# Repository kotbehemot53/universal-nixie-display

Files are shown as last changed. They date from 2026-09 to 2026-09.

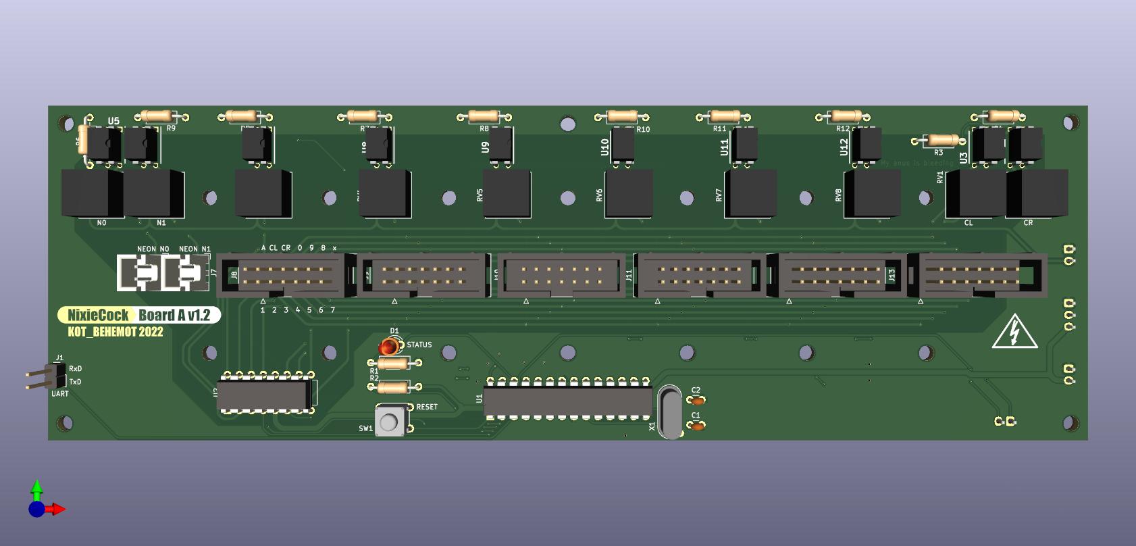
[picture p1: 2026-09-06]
hardware/nixie-board/images/nixie-board-3d-front.jpg

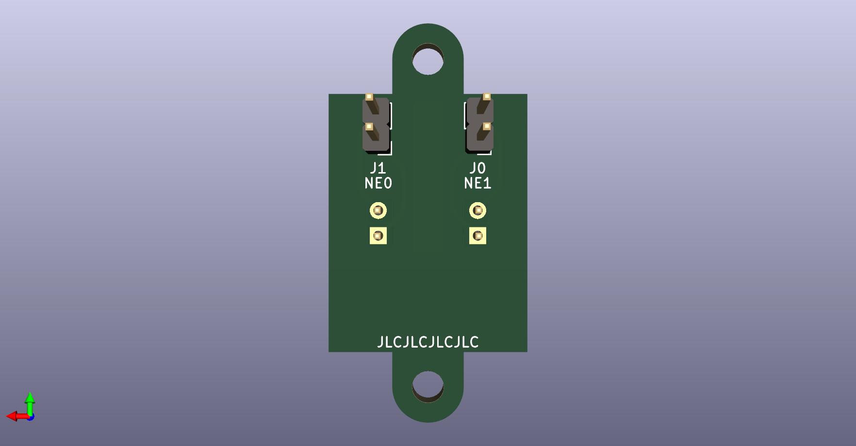
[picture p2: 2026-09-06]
hardware/sockets/neon/images/neonBoard-3d-back.jpg

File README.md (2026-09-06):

Universal Nixie Display
=======================

This is the central project for the open source software and hardware for the Universal Nixie Display.
The display is something more than a desktop nixie clock - it can be whatever you want it to be by
displaying not only time but also weather data or any data you want it to display.

**At the moment it is a work in progress.**

Physical Components
-------------------

The display is modular. Each board works on its own (or with a different master), the default
configuration is:

- **Nixie board** (top): up to 6 nixie tubes (attached via pluggable socket boards with current-limiting
  trimmers, so various nixie models can be used) + up to 2 neon lamps. Driven by an ATmega328P that
  receives commands over I²C (address `0x4`).
- **VFD board** (bottom): one IV-18 8-digit 7-segment VFD tube. Driven by an ATmega328P that receives
  commands over I²C (address `0x5`).
- **Pi hat**: sits on a Raspberry Pi, sends commands to the boards above, takes power from an external
  supply and distributes it, and exposes connectors for control buttons / knobs and the power button.
- **Socket boards**: small per-tube-model boards (IN-14, Z573M) and a neon lamp board that plug into
  the nixie board.

Operating principles
--------------------

The microcontrollers provide low-level control over the displays - multiplexing, dimming, displaying
letters or digits, simple animations. The Raspberry communicates with them using I²C and sends simple
commands (what characters to display, at what brightness etc.). There are python scripts on the
Raspberry that can obtain various data (e.g. weather data from Ruuvi sensors, time from an RTC,
whatever else the user wants) and pass it to be displayed on the nixies and VFD using provided python
libraries that wrap the microcontroller commands in an easy-to-use API.

By default the nixies are meant to be used as the "main" display, whereas the VFD is a "secondary"
display, used to show currently chosen options etc. But it's up to the user to decide how they want to
use them.

Repository layout
-----------------

```
firmware/
  nixie-controller/   PlatformIO project, ATmega328P firmware for the nixie board
  vfd-controller/     PlatformIO project, ATmega328P firmware for the VFD board
software/
  raspberry/          Python scripts + systemd units for the Raspberry Pi master
hardware/
  nixie-board/        KiCad project of the nixie board
  vfd-board/          KiCad project of the VFD board
  pi-hat/             KiCad project of the Raspberry Pi hat
  sockets/            KiCad projects of the tube socket boards (in14, z573m, neon)
  lib/                Shared KiCad symbol / footprint / 3D libraries used by the boards above
scratch/
  kicad-experiments/  Throwaway KiCad experiments, not part of the product
```

See `hardware/README.md` for the board naming history, PCB variants and fabrication files.

Each firmware directory is a self-contained PlatformIO project - open it directly in PlatformIO / your
IDE. Everything in this repository is licensed under the GPLv3 (see `LICENSE`).

History
-------

This repository was assembled from several previous ones (the firmware and Raspberry code used to live
in separate repos pulled in as git submodules, the hardware lived in an older private repo). Their git
histories were rewritten into subdirectories and merged here, so `git log --follow` works on the
imported files. Old feature branches were kept under the `nixie-controller/`, `vfd-controller/` and
`raspberry/` branch prefixes, VFD firmware releases are tagged `vfd-controller/<version>`.

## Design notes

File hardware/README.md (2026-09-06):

Hardware
========

KiCad projects for all boards of the Universal Nixie Display. Files are KiCad 6/7 format
(`kicad_sch` version 20211123 / 20230121, `kicad_pcb` version 20211014 / 20221018), open them with
KiCad 7 or newer and let it upgrade the format when you first save.

```
nixie-board/    top board: up to 6 nixies + 2 neons, ATmega328P, I2C slave 0x4
vfd-board/      bottom board: IV-18 VFD, ATmega328P, I2C slave 0x5
pi-hat/         Raspberry Pi hat: power in, I2C master, buttons / knobs, power button
sockets/
  in14/         IN-14 nixie socket board (plugs into nixie-board)
  z573m/        Z573M nixie socket board (plugs into nixie-board)
  neon/         neon lamp board (plugs into nixie-board)
lib/            shared symbol / footprint / 3D model libraries (see lib/README.md)
```

Every board directory has the same shape:

- `<board>.kicad_pro / .kicad_sch / .kicad_pcb` - the current design,
- `<board>-bom.csv` - BOM exported from the schematic (where one existed),
- `sym-lib-table` / `fp-lib-table` - project library tables, all pointing into `../lib` (or `../../lib`
  for the socket boards) via `${KIPRJMOD}`,
- `fab/` - gerber zips that were actually sent to a fab house, kept as-is for reference,
- `variants/` - alternative PCB layouts of the same schematic (autorouter pre-fills, different track
  styles, earlier revisions). They are standalone `.kicad_pro` + `.kicad_pcb` pairs, open them directly.
  They are kept for reference only, the file next to the `.kicad_sch` is the current one,
- `images/` - schematic exports and 3D renders.

Symbols and footprints are embedded in the schematic / PCB files, so the boards open and render even if
a library entry is missing. The library tables only matter when you want to update a part from its
library.

Checking library resolution
---------------------------

Library links were verified headless with KiCad 10.0.1 (`kicad-cli pcb drc` / `sch erc` with
`--severity-all`, then filter for `lib_footprint_issues` / `lib_symbol_issues`). All project libraries
resolve. The remaining "not found in library" reports come from parts that the *official* KiCad
libraries renamed or removed since the boards were drawn, not from this repository:

| Reference in the design | Boards | Status in KiCad 10 official libs |
|---|---|---|
| `Button_Switch_THT:SW_TH_Tactile_Omron_B3F-10xx` | nixie-board, vfd-board | split into `SW_TH_Tactile_Omron_B3F-100x` / `-102x` / ... |
| `Symbol:Symbol_HighVoltage_Type2_CopperTop_VerySmall`| nixie-board, vfd-board | removed, only `Symbol_HighVoltage_Triangle_*` remain |
| `Connector:Conn_01x02_Male` / `_Female` / `Conn_01x03_Male` / `Conn_01x07_Female` | nixie-board, vfd-board, sockets | moved to `Connector_Generic` |
| `Device:Q_NMOS_SGD`, `Device:Q_NPN_CBE` | pi-hat-tht variant | replaced by `Q_NMOS_GSD` / `Q_NPN_BCE` pin-order variants |

The `variants/` directories carry their own `fp-lib-table` / `sym-lib-table` (same entries, one `../`
deeper), because KiCad treats whatever directory the `.kicad_pro` sits in as the project root.

The embedded copies still work, so nothing needs to change unless a part is re-placed from the library.
"Does not match its copy in the library" warnings are expected for the same reason (embedded 2022/2023
copies vs. current library versions). `kibuzzard-*` footprints are text labels generated by the
KiBuzzard plugin and never had a library.

3D models
---------

Standard-library 3D models are referenced as `${KICAD6_3DMODEL_DIR}/<lib>.3dshapes/<name>.step`. KiCad 7+
maps the old versioned variable to the current install automatically. The references were originally
`.wrl`; KiCad 9+ ships only `.step` files and does *not* fall back from `.wrl` to `.step`, so every
generic part rendered as missing until the extensions were rewritten. Five models were dropped or renamed
upstream and still show as missing in the 3D viewer, which is cosmetic:

| Model | Board |
|---|---|
| `Potentiometer_THT/Potentiometer_Bourns_3386F_Vertical` (9x) | nixie-board |
| `Button_Switch_THT/SW_TH_Tactile_Omron_B3F-10xx` | vfd-board |
| `Module/Raspberry_Pi_Zero_Socketed_THT_FaceDown_MountingHoles` | vfd-board, pi-hat |
| `Connector_USB/USB_Micro-B_Amphenol_10103594-0001LF_Horizontal` | pi-hat |
| `Connector_Wire/SolderWire-0.75sqmm_1x02_P4.8mm_D1.25mm_OD2.3mm`  | pi-hat |

Vendored SamacSys models live in `lib/SamacSys_Parts.3dshapes/` and are referenced via `${KIPRJMOD}`.

Naming history
--------------

The boards were renamed when the projects were moved into this repository. Old names still appear in
title blocks, net names and library nicknames (`Nixiecock1`, `nixieCockB`), which were intentionally
left alone so nothing inside the design files had to be touched apart from 3D model paths.

| Old project (piclock repo) | Here | Notes |
|---|---|---|
| `kicad/nixiecock1` | `nixie-board` | "Board A" |
| `kicad/nixiecockB` | `vfd-board` | "Board B" |
| `kicad/pihat/pihat` `pihat_smd.kicad_sch/.kicad_pro` | `pi-hat`  | SMD version, current schematic |
| `kicad/pihat/pihat` `pihat_smd-rounded-blah.kicad_pcb` | `pi-hat.kicad_pcb` | current layout (rounded tracks), the one that was fabbed |
| `kicad/pihat/pihat` `pihat_smd.kicad_pcb` | `pi-hat/variants/pi-hat_unrounded` | same layout before track rounding |
| `kicad/pihat/pihat` `pihat.*` | `pi-hat/variants/pi-hat-tht` | older THT version, has its own schematic |
| `kicad/IN-14Board` | `sockets/in14` | file names unchanged (`in14board.*`) |
| `kicad/z573mBoard` | `sockets/z573m` | file names unchanged (`z573mBoard.*`) |
| `kicad/neonBoard` | `sockets/neon` | file names unchanged (`neonBoard.*`) |
| `kicad/xprmnt` | `../scratch/kicad-experiments` | was gitignored before |

Fabrication files vs. layouts (from file timestamps, verify before reusing):

- `pi-hat/fab/gerber5.zip` matches `pi-hat.kicad_pcb` (the rounded-track layout).
- `nixie-board/fab/gerber_A2`, `gerber_A3` and `vfd-board/fab/gerber_B1..B3` predate the last PCB
  edits of those boards; treat the highest number as the last one ordered.
- `sockets/in14/fab/gerbers7.zip` and `sockets/z573m/fab/gerber3.zip` match the current PCBs.

What was dropped on import
--------------------------

Regenerable or per-user files were not carried over: `*-backups/`, `.history/`, `fp-info-cache`,
`*.kicad_prl`, `*.kicad_sch-bak`, `*.xml` netlists, lock files, unzipped gerber directories that also
existed as zips, and the vendor library zips (`KiCadLibs-master.zip`, SamacSys `LIB_*.zip`) whose
relevant content is now in `lib/`.

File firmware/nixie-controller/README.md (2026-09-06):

Universal Nixie Display
=======================

Nixie microcontroller
---------------------

Hardware: Atmega328p

*This is a work in progress*

Controls the Board A of the Universal Nixie Display (the Nixie module).
Receives commands via I²C.

The current device address is `0x4`.

Available commands
------------------

See the `CMD_` constants in `main.cpp` and their comments.

TODO
----

- refactor the code based on the current VFD Display Firmware architecture
  (`../vfd-controller`).

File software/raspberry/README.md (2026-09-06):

Universal Nixie Display
=======================

Raspberry master
----------------

Hardware: Raspberry Pi Zero W or any other with Wi-Fi support

*This is a work in progress*

Reads signals from an external control panel and runs appropriate features on the Universal Nixie Display boards A and B.

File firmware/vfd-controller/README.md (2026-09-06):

Universal Nixie Display
=======================

VFD microcontroller
-------------------

Hardware: Atmega328p

*This is a work in progress*

Controls the Board B of the Universal Nixie Display (the VFD module).
Receives commands via I²C.

The current device address is `0x5`.

Available commands
------------------

Defined in `IV18I2CCommandExecutor.h`.
See the public constants and their comments there. 

The "instant commands" will be run within the same frame during which they are received.

The "bunchable commands" will be run when `CMD_MULTI_FINISH` instant command is received, all at once, in the order
in which they were sent.

Some commands require a following byte to be sent, to set a value (see command comments).
Not sending the required following byte will result in an undefined behaviour.

TODO
----

- add CMakeLists.txt to git?
- make a fresh platformio deployment instruction;

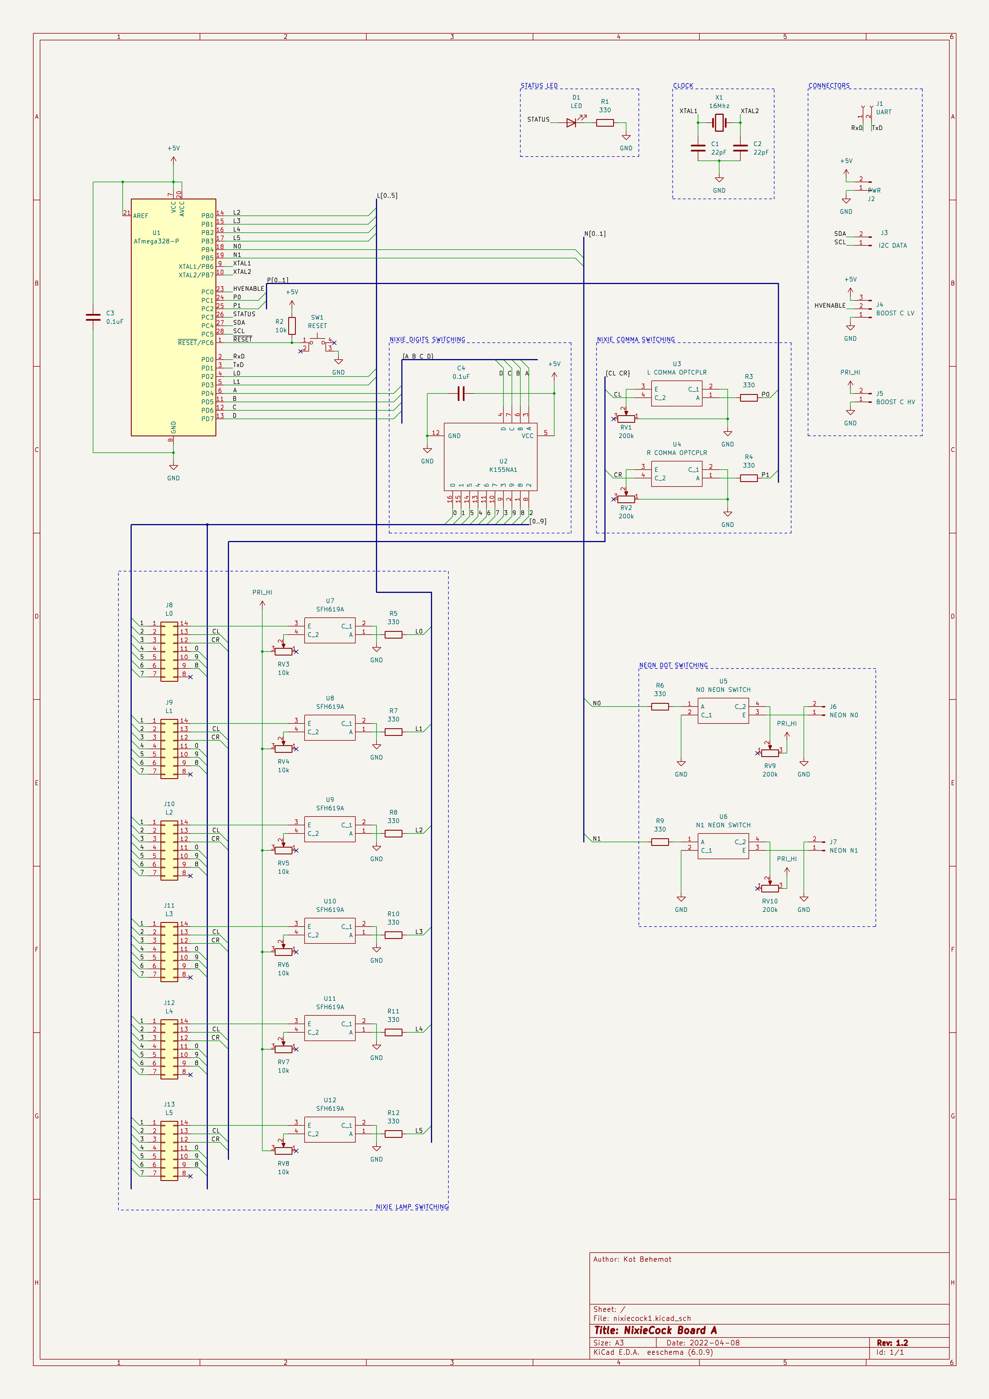
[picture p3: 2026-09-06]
hardware/nixie-board/images/nixie-board-schematic.png

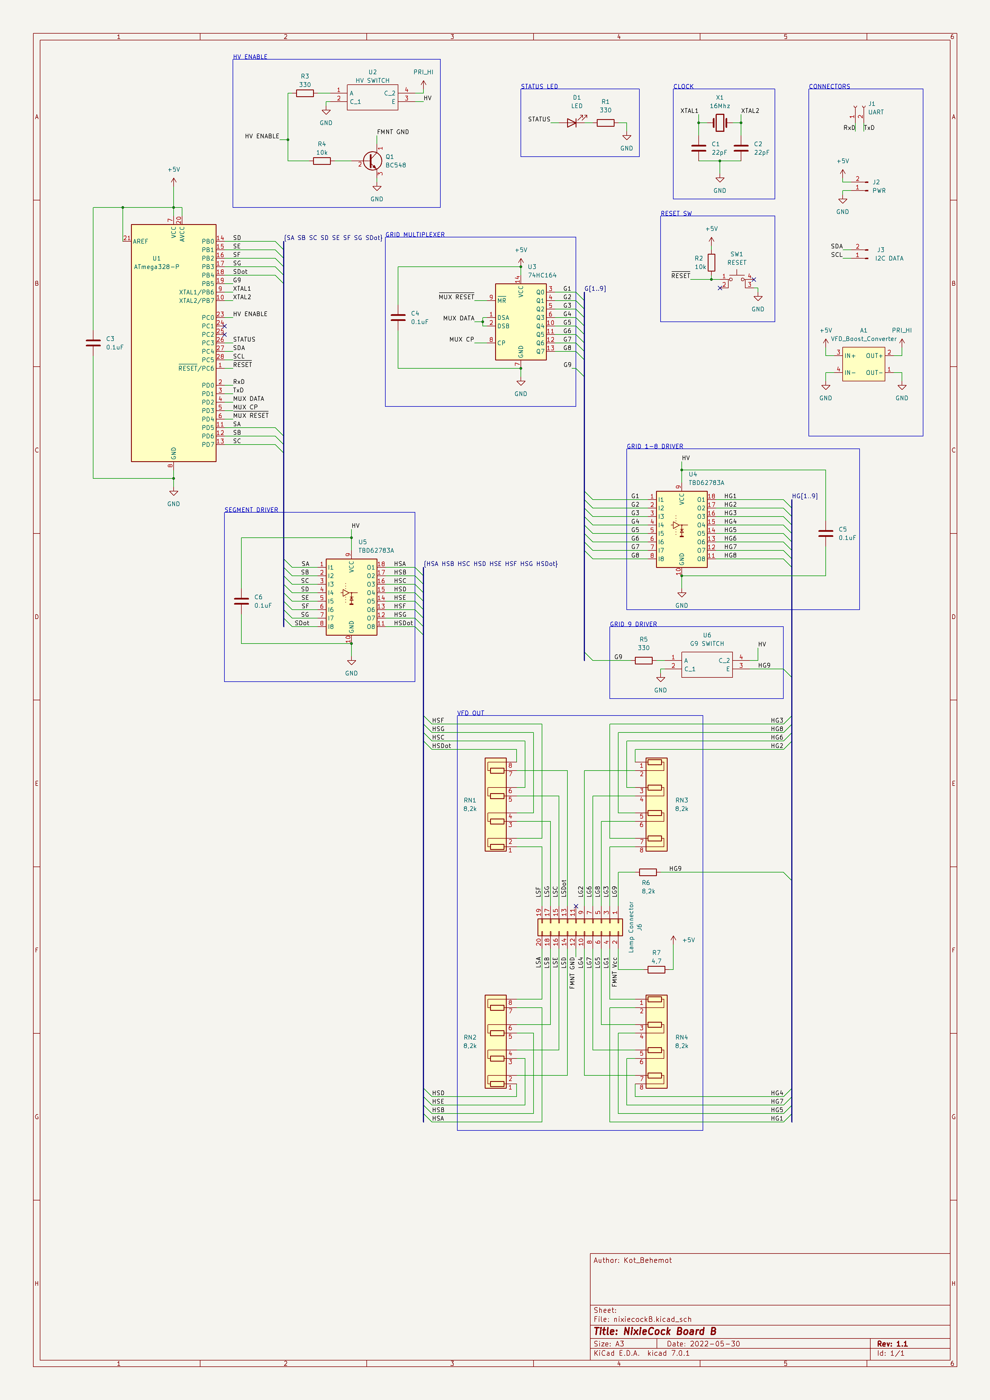
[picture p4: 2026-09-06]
firmware/vfd-controller/doc/vfd_board_schematic.png

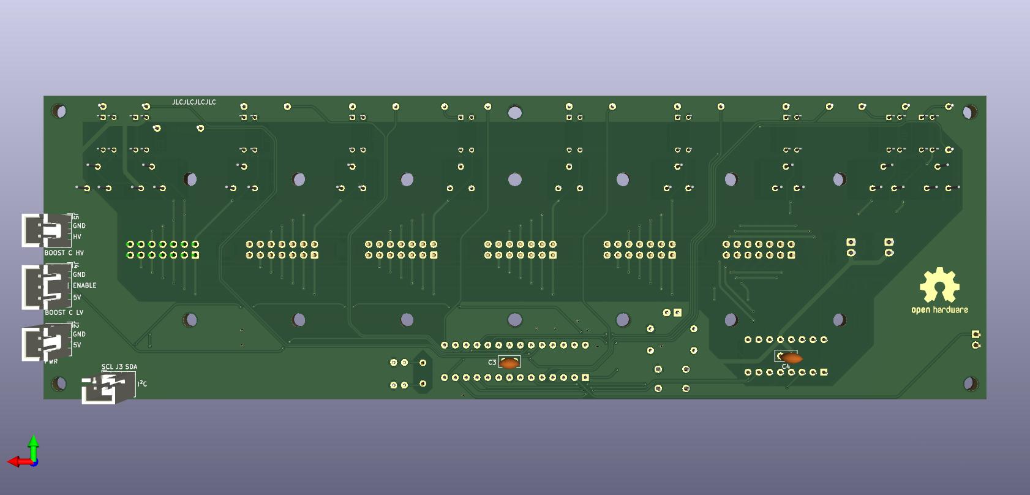
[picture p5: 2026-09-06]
hardware/nixie-board/images/nixie-board-3d-back.jpg

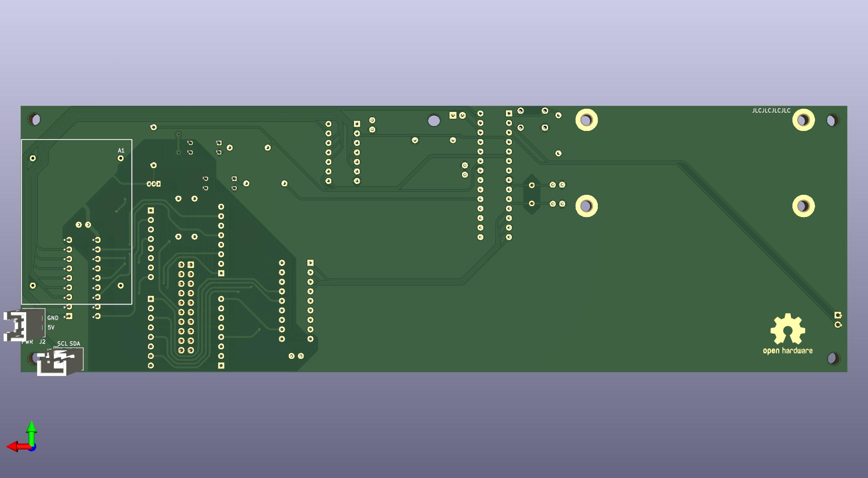
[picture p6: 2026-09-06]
hardware/vfd-board/images/vfd-board-3d-back.jpg

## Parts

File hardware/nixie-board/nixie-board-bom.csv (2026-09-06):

Source: | H:\_Moje_dydy\Documents\Projekty\__sources\piclock\kicad\nixiecock1\nixiecock1.kicad_sch
Date: | 25.06.2022 10:36:41
Tool: | Eeschema (6.0.0)
Generator: | E:\Programy\KiCad\6.0\bin\scripting\plugins/bom_csv_grouped_by_value_with_fp.py
Component Count: | 54
Ref | Qnty | Value | Cmp name | Footprint | Description | Vendor
C1, C2, | 2 | 22pF | C | Capacitor_THT:C_Disc_D3.0mm_W1.6mm_P2.50mm | Unpolarized capacitor
C3, C4, | 2 | 0.1uF | C | Capacitor_THT:C_Disc_D5.0mm_W2.5mm_P2.50mm | Unpolarized capacitor
D1, | 1 | LED | LED | LED_THT:LED_D3.0mm | Light emitting diode
J1, | 1 | UART | Conn_01x02_Female | Connector_PinHeader_2.54mm:PinHeader_1x02_P2.54mm_Vertical | Generic connector, single row, 01x02, script generated (kicad-library-utils/schlib/autogen/connector/)
J2, | 1 | PWR | Conn_01x02_Male_3 | Connector_JST:JST_XH_B2B-XH-A_1x02_P2.50mm_Vertical | Generic connector, single row, 01x02, script generated (kicad-library-utils/schlib/autogen/connector/)
J3, | 1 | I2C DATA | Conn_01x02_Male | Connector_JST:JST_XH_B2B-XH-A_1x02_P2.50mm_Vertical | Generic connector, single row, 01x02, script generated (kicad-library-utils/schlib/autogen/connector/)
J4, | 1 | BOOST C LV | Conn_01x03_Male | Connector_JST:JST_XH_B3B-XH-A_1x03_P2.50mm_Vertical | Generic connector, single row, 01x03, script generated (kicad-library-utils/schlib/autogen/connector/)
J5, | 1 | BOOST C HV | Conn_01x02_Male_2 | Connector_JST:JST_XH_B2B-XH-A_1x02_P2.50mm_Vertical | Generic connector, single row, 01x02, script generated (kicad-library-utils/schlib/autogen/connector/)
J6, | 1 | NEON N0 | Conn_01x02_Male_1 | Connector_JST:JST_XH_B2B-XH-A_1x02_P2.50mm_Vertical | Generic connector, single row, 01x02, script generated (kicad-library-utils/schlib/autogen/connector/)
J7, | 1 | NEON N1 | Conn_01x02_Male_1 | Connector_JST:JST_XH_B2B-XH-A_1x02_P2.50mm_Vertical | Generic connector, single row, 01x02, script generated (kicad-library-utils/schlib/autogen/connector/)
J8, | 1 | L0 | Conn_02x07_Counter_Clockwise | Connector_IDC:IDC-Header_2x07_P2.54mm_Vertical | Generic connector, double row, 02x07, counter clockwise pin numbering scheme (similar to DIP packge numbering), script generated (kicad-library-utils/schlib/autogen/connector/)
J9, | 1 | L1 | Conn_02x07_Counter_Clockwise | Connector_IDC:IDC-Header_2x07_P2.54mm_Vertical | Generic connector, double row, 02x07, counter clockwise pin numbering scheme (similar to DIP packge numbering), script generated (kicad-library-utils/schlib/autogen/connector/)
J10, | 1 | L2 | Conn_02x07_Counter_Clockwise | Connector_IDC:IDC-Header_2x07_P2.54mm_Vertical | Generic connector, double row, 02x07, counter clockwise pin numbering scheme (similar to DIP packge numbering), script generated (kicad-library-utils/schlib/autogen/connector/)
J11, | 1 | L3 | Conn_02x07_Counter_Clockwise | Connector_IDC:IDC-Header_2x07_P2.54mm_Vertical | Generic connector, double row, 02x07, counter clockwise pin numbering scheme (similar to DIP packge numbering), script generated (kicad-library-utils/schlib/autogen/connector/)
J12, | 1 | L4 | Conn_02x07_Counter_Clockwise | Connector_IDC:IDC-Header_2x07_P2.54mm_Vertical | Generic connector, double row, 02x07, counter clockwise pin numbering scheme (similar to DIP packge numbering), script generated (kicad-library-utils/schlib/autogen/connector/)
J13, | 1 | L5 | Conn_02x07_Counter_Clockwise | Connector_IDC:IDC-Header_2x07_P2.54mm_Vertical | Generic connector, double row, 02x07, counter clockwise pin numbering scheme (similar to DIP packge numbering), script generated (kicad-library-utils/schlib/autogen/connector/)
R1, R3, R4, R5, R6, R7, R8, R9, R10, R11, R12, | 11 | 330 | R | Resistor_THT:R_Axial_DIN0207_L6.3mm_D2.5mm_P10.16mm_Horizontal | Resistor
R2, | 1 | 10k | R | Resistor_THT:R_Axial_DIN0207_L6.3mm_D2.5mm_P10.16mm_Horizontal | Resistor
RV1, RV2, RV9, RV10, | 4 | 200k | R_Potentiometer | Potentiometer_THT:Potentiometer_Bourns_3386F_Vertical | Potentiometer
RV3, RV4, RV5, RV6, RV7, RV8, | 6 | 10k | R_Potentiometer | Potentiometer_THT:Potentiometer_Bourns_3386F_Vertical | Potentiometer
SW1, | 1 | RESET | SW_MEC_5E | Button_Switch_THT:SW_TH_Tactile_Omron_B3F-10xx | MEC 5E single pole normally-open tactile switch
U1, | 1 | ATmega328-P | ATmega328-P | Package_DIP:DIP-28_W7.62mm | 20MHz, 32kB Flash, 2kB SRAM, 1kB EEPROM, DIP-28
U2, | 1 | K155NA1 | K155NA1 | Package_DIP:DIP-16_W7.62mm | Nixie tube driver // BCD to decimal
U3, | 1 | L COMMA OPTCPLR | SFH619A | SamacSys_Parts:DIP762W56P254L469H470Q4N | Vishay SFH619A DC Input Photodarlington Output Optocoupler, Through Hole, 4-Pin DIP
U4, | 1 | R COMMA OPTCPLR | SFH619A | SamacSys_Parts:DIP762W56P254L469H470Q4N | Vishay SFH619A DC Input Photodarlington Output Optocoupler, Through Hole, 4-Pin DIP
U5, | 1 | N0 NEON SWITCH | SFH619A | SamacSys_Parts:DIP762W56P254L469H470Q4N | Vishay SFH619A DC Input Photodarlington Output Optocoupler, Through Hole, 4-Pin DIP
U6, | 1 | N1 NEON SWITCH | SFH619A | SamacSys_Parts:DIP762W56P254L469H470Q4N | Vishay SFH619A DC Input Photodarlington Output Optocoupler, Through Hole, 4-Pin DIP
U7, U8, U9, U10, U11, U12, | 6 | SFH619A | SFH619A | SamacSys_Parts:DIP762W56P254L469H470Q4N | Vishay SFH619A DC Input Photodarlington Output Optocoupler, Through Hole, 4-Pin DIP
X1, | 1 | 16Mhz | Crystal | Crystal:Crystal_HC49-4H_Vertical | Two pin crystal

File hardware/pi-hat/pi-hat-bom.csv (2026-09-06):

Source: | E:\_Moje_dydy\Documents\Projekty\__sources\piclock\kicad\pihat\pihat\pihat_smd.kicad_sch
Date: | 21.03.2023 13:07:37
Tool: | Eeschema 7.0.1
Generator: | D:\Programy\KiCad\7.0\bin\scripting\plugins/bom_csv_grouped_by_value.py
Component Count: | 31
Collated Components:
Item | Qty | Reference(s) | Value | LibPart | Footprint | Datasheet | DNP | Sim.Device | Sim.Pins
1 | 2 | D1, D2 | 1N4148W | Diode:1N4148W | Diode_SMD:D_SOD-123 | https://www.vishay.com/docs/85748/1n4148w.pdf |  | D | 1=K 2=A
2 | 1 | J1 | ENC_1 | Connector_Generic:Conn_01x05 | Connector_JST:JST_XH_S5B-XH-A_1x05_P2.50mm_Horizontal | ~
3 | 1 | J2 | ENC_2 | Connector_Generic:Conn_01x05 | Connector_JST:JST_XH_S5B-XH-A_1x05_P2.50mm_Horizontal | ~
4 | 1 | J3 | BTN_1 | Connector_Generic:Conn_01x02 | Connector_JST:JST_XH_B2B-XH-A_1x02_P2.50mm_Vertical | ~
5 | 1 | J4 | BTN_2 | Connector_Generic:Conn_01x02 | Connector_JST:JST_XH_B2B-XH-A_1x02_P2.50mm_Vertical | ~
6 | 1 | J5 | BTN_3 | Connector_Generic:Conn_01x02 | Connector_JST:JST_XH_B2B-XH-A_1x02_P2.50mm_Vertical | ~
7 | 1 | J6 | Raspberry | Connector_Generic:Conn_02x20_Odd_Even | Connector_PinSocket_2.54mm:PinSocket_2x20_P2.54mm_Vertical | ~
8 | 1 | J7 | PWR_IN | Connector:USB_B_Micro | Connector_USB:USB_Micro-B_Amphenol_10103594-0001LF_Horizontal | ~
9 | 1 | J8 | PWR_OUT_PI | Connector_Generic:Conn_01x02 | Connector_Wire:SolderWire-0.75sqmm_1x02_P4.8mm_D1.25mm_OD2.3mm | ~
10 | 1 | J9 | PWR_OUT_A | Connector_Generic:Conn_01x02 | Connector_JST:JST_XH_B2B-XH-A_1x02_P2.50mm_Vertical | ~
11 | 1 | J10 | PWR_OUT_B | Connector_Generic:Conn_01x02 | Connector_JST:JST_XH_B2B-XH-A_1x02_P2.50mm_Vertical | ~
12 | 1 | J11 | I2C_OUT_A | Connector_Generic:Conn_01x02 | Connector_JST:JST_XH_B2B-XH-A_1x02_P2.50mm_Vertical | ~
13 | 1 | J12 | BOARDS_RESET | Connector_Generic:Conn_01x02 | Connector_JST:JST_XH_B2B-XH-A_1x02_P2.50mm_Vertical | ~
14 | 1 | J13 | EXT_PWR_LED | Connector_Generic:Conn_01x02 | Connector_JST:JST_XH_B2B-XH-A_1x02_P2.50mm_Vertical | ~
15 | 1 | J14 | I2C_OUT_B | Connector_Generic:Conn_01x02 | Connector_JST:JST_XH_B2B-XH-A_1x02_P2.50mm_Vertical | ~
16 | 3 | Q1, Q2, Q3 | BC846 | Transistor_BJT:BC846 | Package_TO_SOT_SMD:SOT-23 | https://assets.nexperia.com/documents/data-sheet/BC846_SER.pdf
17 | 2 | Q4, Q5 | BSS138 | Transistor_FET:BSS138 | Package_TO_SOT_SMD:SOT-23 | https://www.onsemi.com/pub/Collateral/BSS138-D.PDF
18 | 6 | R1, R3, R6, R7, R8, R9 | 10k | Device:R | Resistor_SMD:R_0805_2012Metric_Pad1.20x1.40mm_HandSolder | ~
19 | 3 | R2, R4, R5 | 100k | Device:R | Resistor_SMD:R_0805_2012Metric_Pad1.20x1.40mm_HandSolder | ~
20 | 1 | SW1 | SW_Push | Switch:SW_Push | Connector_JST:JST_XH_B2B-XH-A_1x02_P2.50mm_Vertical | ~

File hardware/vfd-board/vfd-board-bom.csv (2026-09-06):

Source: | H:\_Moje_dydy\Documents\Projekty\__sources\piclock\kicad\nixiecockB\nixiecockB.kicad_sch
Date: | 25.06.2022 10:28:06
Tool: | Eeschema (6.0.0)
Generator: | E:\Programy\KiCad\6.0\bin\scripting\plugins/bom_csv_grouped_by_value_with_fp.py
Component Count: | 32
Ref | Qnty | Value | Cmp name | Footprint | Description | Vendor
A1, | 1 | VFD_Boost_Converter | VFD_Boost_Converter | nixieCockB:VFD Boost Converter
C1, C2, | 2 | 22pF | C | Capacitor_THT:C_Disc_D3.0mm_W1.6mm_P2.50mm | Unpolarized capacitor
C3, C4, C5, C6, | 4 | 0.1uF | C | Capacitor_THT:C_Disc_D5.0mm_W2.5mm_P2.50mm | Unpolarized capacitor
D1, | 1 | LED | LED | LED_THT:LED_D3.0mm | Light emitting diode
J1, | 1 | UART | Conn_01x02_Female | Connector_PinHeader_2.54mm:PinHeader_1x02_P2.54mm_Vertical | Generic connector, single row, 01x02, script generated (kicad-library-utils/schlib/autogen/connector/)
J2, | 1 | PWR | Conn_01x02_Male_3 | Connector_JST:JST_XH_B2B-XH-A_1x02_P2.50mm_Vertical | Generic connector, single row, 01x02, script generated (kicad-library-utils/schlib/autogen/connector/)
J3, | 1 | I2C DATA | Conn_01x02_Male | Connector_JST:JST_XH_B2B-XH-A_1x02_P2.50mm_Vertical | Generic connector, single row, 01x02, script generated (kicad-library-utils/schlib/autogen/connector/)
J6, | 1 | Lamp Connector | Conn_02x10_Odd_Even | Connector_IDC:IDC-Header_2x10_P2.54mm_Vertical | Generic connector, double row, 02x10, odd/even pin numbering scheme (row 1 odd numbers, row 2 even numbers), script generated (kicad-library-utils/schlib/autogen/connector/)
Q1, | 1 | BC548 | BC548 | Package_TO_SOT_THT:TO-92_Inline | 0.1A Ic, 30V Vce, Small Signal NPN Transistor, TO-92
R1, R3, R5, | 3 | 330 | R | Resistor_THT:R_Axial_DIN0207_L6.3mm_D2.5mm_P10.16mm_Horizontal | Resistor
R2, R4, | 2 | 10k | R | Resistor_THT:R_Axial_DIN0207_L6.3mm_D2.5mm_P10.16mm_Horizontal | Resistor
R6, | 1 | 8,2k | R | Resistor_THT:R_Axial_DIN0207_L6.3mm_D2.5mm_P10.16mm_Horizontal | Resistor
R7, | 1 | 4,7 | R | Resistor_THT:R_Axial_DIN0207_L6.3mm_D2.5mm_P10.16mm_Horizontal | Resistor
RN1, RN2, RN3, RN4, | 4 | 8,2k | R_Pack04_SIP | Resistor_THT:R_Array_SIP8 | 4 resistor network, parallel topology, SIP package
SW1, | 1 | RESET | SW_MEC_5E | Button_Switch_THT:SW_TH_Tactile_Omron_B3F-10xx | MEC 5E single pole normally-open tactile switch
U1, | 1 | ATmega328-P | ATmega328-P | Package_DIP:DIP-28_W7.62mm_Socket | 20MHz, 32kB Flash, 2kB SRAM, 1kB EEPROM, DIP-28
U2, | 1 | HV SWITCH | SFH619A | SamacSys_Parts:DIP762W56P254L469H470Q4N | Vishay SFH619A DC Input Photodarlington Output Optocoupler, Through Hole, 4-Pin DIP
U3, | 1 | 74HC164 | 74HC164 | Package_DIP:DIP-14_W7.62mm_Socket | 8-bit serial-in parallel-out shift register
U4, U5, | 2 | TBD62783A | TBD62783A | Package_DIP:DIP-18_W7.62mm_Socket | 8-Channel Source Type Transistor Array, TTL and CMOS compatible, 500mA, 50V, DIP-18/SOP-18/SSOP-18/SOIC-18W
U6, | 1 | G9 SWITCH | SFH619A | SamacSys_Parts:DIP762W56P254L469H470Q4N | Vishay SFH619A DC Input Photodarlington Output Optocoupler, Through Hole, 4-Pin DIP
X1, | 1 | 16Mhz | Crystal | Crystal:Crystal_HC49-4H_Vertical | Two pin crystal

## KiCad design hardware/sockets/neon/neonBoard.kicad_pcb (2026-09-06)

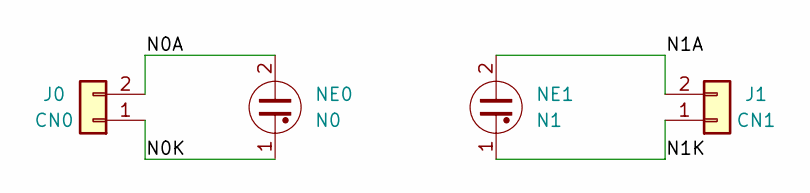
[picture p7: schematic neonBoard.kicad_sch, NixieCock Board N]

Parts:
J0: CN0; PinHeader_1x02_P2.54mm_Vertical
J1: CN1; PinHeader_1x02_P2.54mm_Vertical
NE0: N0; PinHeader_1x02_P2.54mm_Vertical
NE1: N1; PinHeader_1x02_P2.54mm_Vertical

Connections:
/N0A: J0.2, NE0.2
/N0K: J0.1, NE0.1
/N1A: J1.2, NE1.2
/N1K: J1.1, NE1.1

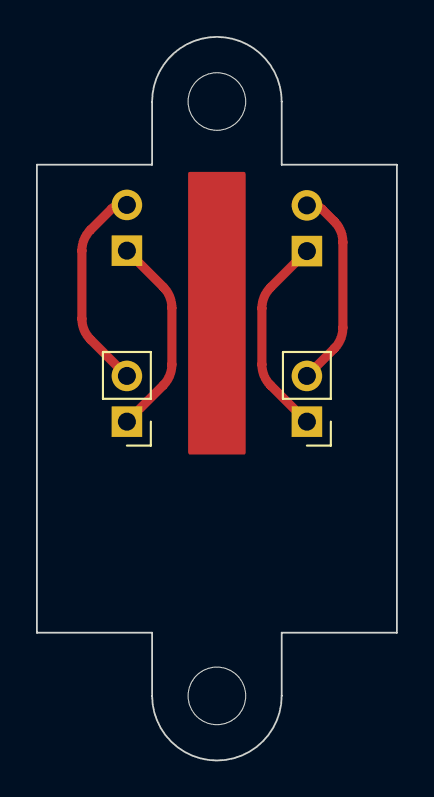
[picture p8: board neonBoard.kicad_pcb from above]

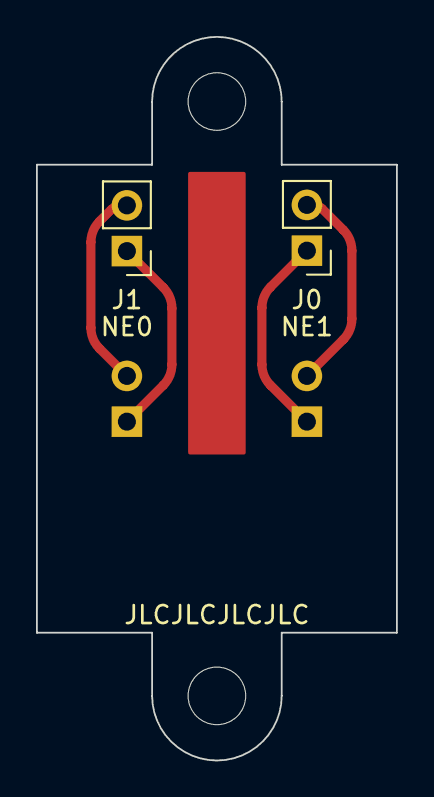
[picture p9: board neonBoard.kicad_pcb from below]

Board: 2 copper layers, 20.0 x 40.2 mm, 4 parts (2 on the bottom side), 4 nets.

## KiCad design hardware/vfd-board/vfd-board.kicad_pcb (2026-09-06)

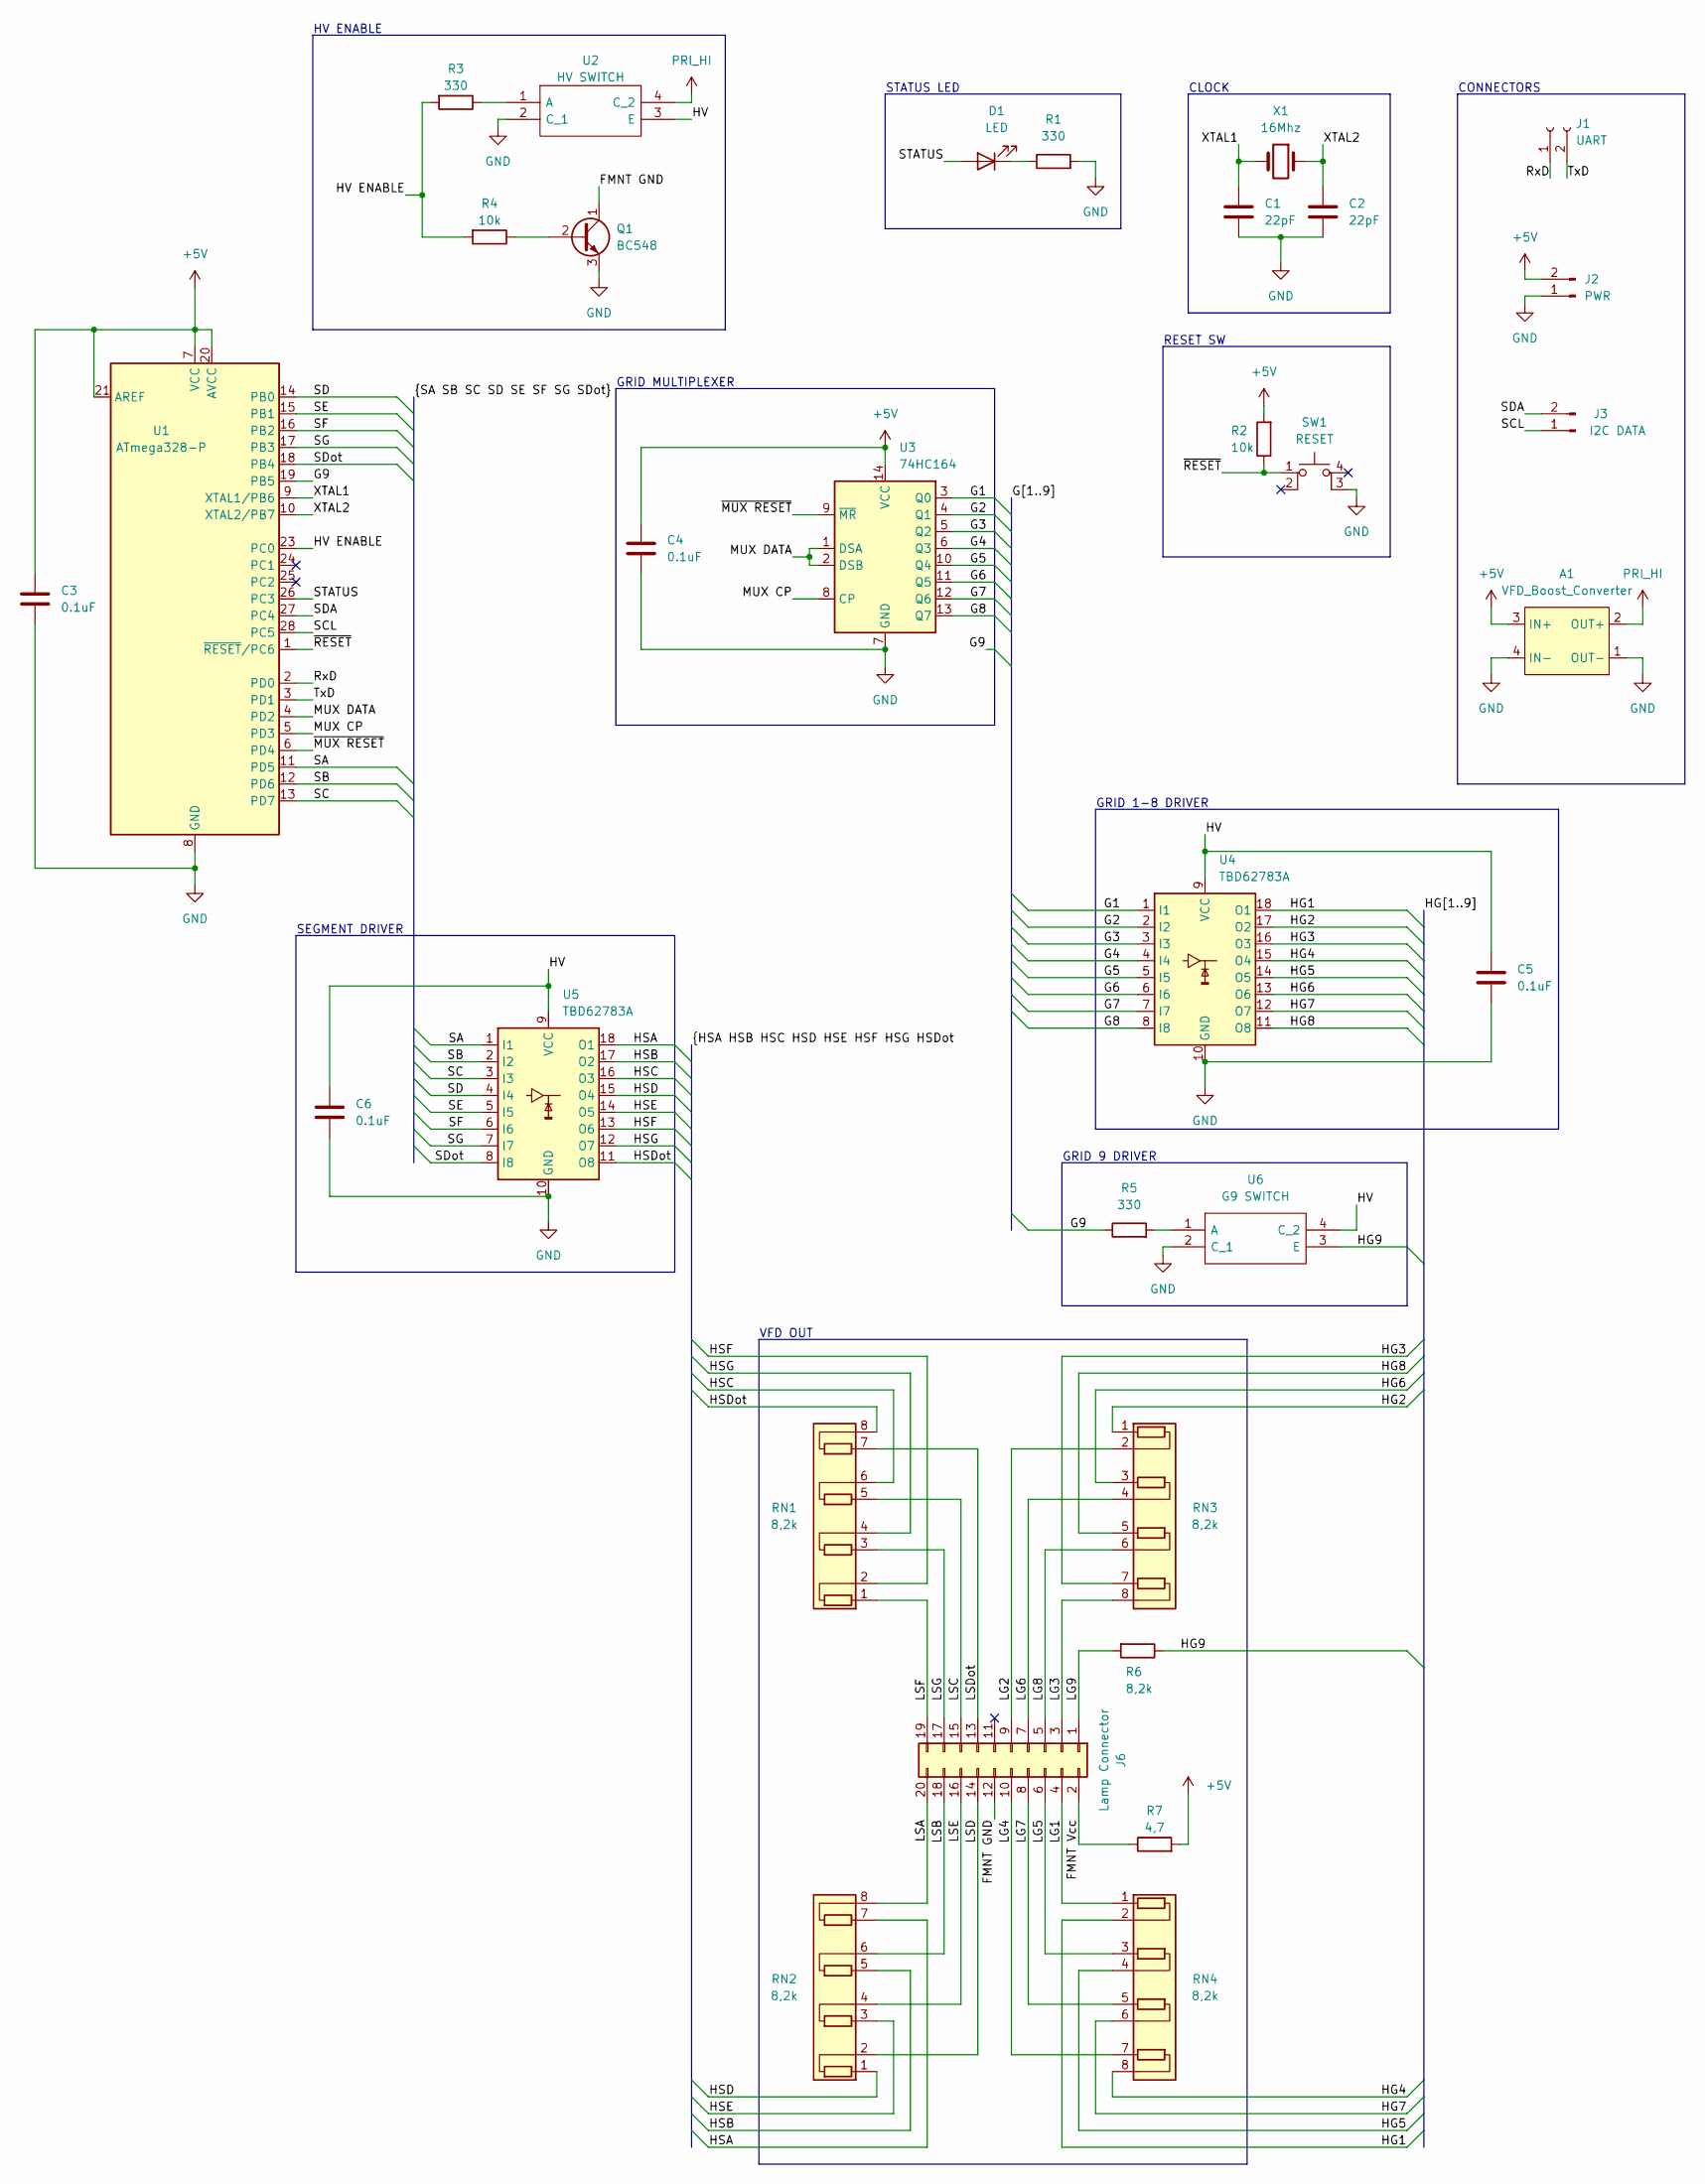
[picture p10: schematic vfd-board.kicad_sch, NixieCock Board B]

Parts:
A1: VFD_Boost_Converter; VFD Boost Converter
C1, C2: 22pF; C_Disc_D3.0mm_W1.6mm_P2.50mm
C3, C4, C5, C6: 0.1uF; C_Disc_D5.0mm_W2.5mm_P2.50mm
D1: LED; LED_D3.0mm
J1: UART; PinHeader_1x02_P2.54mm_Vertical
J2: PWR; JST_XH_B2B-XH-A_1x02_P2.50mm_Vertical
J3: I2C DATA; JST_XH_B2B-XH-A_1x02_P2.50mm_Vertical
J6: Lamp Connector; IDC-Header_2x10_P2.54mm_Vertical
Q1: BC548; TO-92_Inline
R1, R3, R5: 330; R_Axial_DIN0207_L6.3mm_D2.5mm_P10.16mm_Horizontal
R2, R4: 10k; R_Axial_DIN0207_L6.3mm_D2.5mm_P10.16mm_Horizontal
R6: 8,2k; R_Axial_DIN0207_L6.3mm_D2.5mm_P10.16mm_Horizontal
R7: 4,7; R_Axial_DIN0207_L6.3mm_D2.5mm_P10.16mm_Horizontal
RN1, RN2, RN3, RN4: 8,2k; R_Array_SIP8
SW1: RESET; SW_TH_Tactile_Omron_B3F-10xx
U1: ATmega328-P; DIP-28_W7.62mm_Socket
U2: HV SWITCH; DIP762W56P254L469H470Q4N; Mouser Part Number 782-SFH619A
U3: 74HC164; DIP-14_W7.62mm_Socket
U4, U5: TBD62783A; DIP-18_W7.62mm_Socket
U6: G9 SWITCH; DIP762W56P254L469H470Q4N; Mouser Part Number 782-SFH619A
X1: 16Mhz; Crystal_HC49-4H_Vertical

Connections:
+5V: A1.3 (IN+), C3.1, C4.1, J2.2, R2.2, R7.2, U1.7 (VCC), U1.20 (AVCC), U1.21 (AREF), U3.14 (VCC)
/FMNT GND: J6.12, Q1.1 (C)
/FMNT Vcc: J6.2, R7.1
/G1: U3.3 (Q0), U4.1 (I1)
/G2: U3.4 (Q1), U4.2 (I2)
/G3: U3.5 (Q2), U4.3 (I3)
/G4: U3.6 (Q3), U4.4 (I4)
/G5: U3.10 (Q4), U4.5 (I5)
/G6: U3.11 (Q5), U4.6 (I6)
/G7: U3.12 (Q6), U4.7 (I7)
/G8: U3.13 (Q7), U4.8 (I8)
/G9: R5.1, U1.19 (PB5)
/HG1: RN4.2 (R1.2), U4.18 (O1)
/HG2: RN3.1 (R1.1), U4.17 (O2)
/HG3: RN3.7 (R4.1), U4.16 (O3)
/HG4: RN4.8 (R4.2), U4.15 (O4)
/HG5: RN4.4 (R2.2), U4.14 (O5)
/HG6: RN3.3 (R2.1), U4.13 (O6)
/HG7: RN4.6 (R3.2), U4.12 (O7)
/HG8: RN3.5 (R3.1), U4.11 (O8)
/HG9: R6.1, U6.3 (E)
/HSA: RN2.7 (R4.1), U5.18 (O1)
/HSB: RN2.5 (R3.1), U5.17 (O2)
/HSC: RN1.6 (R3.2), U5.16 (O3)
/HSD: RN2.1 (R1.1), U5.15 (O4)
/HSDot: RN1.8 (R4.2), U5.11 (O8)
/HSE: RN2.3 (R2.1), U5.14 (O5)
/HSF: RN1.2 (R1.2), U5.13 (O6)
/HSG: RN1.4 (R2.2), U5.12 (O7)
/HV: C5.1, C6.1, U2.3 (E), U4.9 (VCC), U5.9 (VCC), U6.4 (C_2)
/HV ENABLE: R3.2, R4.2, U1.23 (PC0)
/LG1: J6.4, RN4.1 (R1.1)
/LG2: J6.9, RN3.2 (R1.2)
/LG3: J6.3, RN3.8 (R4.2)
/LG4: J6.10, RN4.7 (R4.1)
/LG5: J6.6, RN4.3 (R2.1)
/LG6: J6.7, RN3.4 (R2.2)
/LG7: J6.8, RN4.5 (R3.1)
/LG8: J6.5, RN3.6 (R3.2)
/LG9: J6.1, R6.2
/LSA: J6.20, RN2.8 (R4.2)
/LSB: J6.18, RN2.6 (R3.2)
/LSC: J6.15, RN1.5 (R3.1)
/LSD: J6.14, RN2.2 (R1.2)
/LSDot: J6.13, RN1.7 (R4.1)
/LSE: J6.16, RN2.4 (R2.2)
/LSF: J6.19, RN1.1 (R1.1)
/LSG: J6.17, RN1.3 (R2.1)
/MUX CP: U1.5 (PD3), U3.8 (CP)
/MUX DATA: U1.4 (PD2), U3.1 (DSA), U3.2 (DSB)
/RxD: J1.1, U1.2 (PD0)
/SA: U1.11 (PD5), U5.1 (I1)
/SB: U1.12 (PD6), U5.2 (I2)
/SC: U1.13 (PD7), U5.3 (I3)
/SCL: J3.1, U1.28 (PC5)
/SD: U1.14 (PB0), U5.4 (I4)
/SDA: J3.2, U1.27 (PC4)
/SDot: U1.18 (PB4), U5.8 (I8)
/SE: U1.15 (PB1), U5.5 (I5)
/SF: U1.16 (PB2), U5.6 (I6)
/SG: U1.17 (PB3), U5.7 (I7)
/STATUS: D1.2 (A), U1.26 (PC3)
/TxD: J1.2, U1.3 (PD1)
/XTAL1: C1.1, U1.9 (XTAL1/PB6), X1.2
/XTAL2: C2.1, U1.10 (XTAL2/PB7), X1.1
/~MUX RESET: U1.6 (PD4), U3.9 (~MR)
/~RESET: R2.1, SW1.1, U1.1 (~RESET/PC6)
GND: A1.1 (OUT-), A1.4 (IN-), C1.2, C2.2, C3.2, C4.2, C5.2, C6.2, J2.1, Q1.3 (E), R1.2, SW1.3 (K), U1.8 (GND), U1.22 (GND), U2.2 (C_1), U3.7 (GND), U4.10 (GND), U5.10 (GND), U6.2 (C_1)
unnamed: D1.1 (K), R1.1
unnamed: Q1.2 (B), R4.1
unnamed: R3.1, U2.1 (A)
unnamed: R5.2, U6.1 (A)
PRI_HI: A1.2 (OUT+), U2.4 (C_2)

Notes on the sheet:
RESET SW
GRID 1-8 DRIVER
GRID 9 DRIVER
SEGMENT DRIVER
VFD OUT
GRID MULTIPLEXER
STATUS LED
CONNECTORS
CLOCK
HV ENABLE

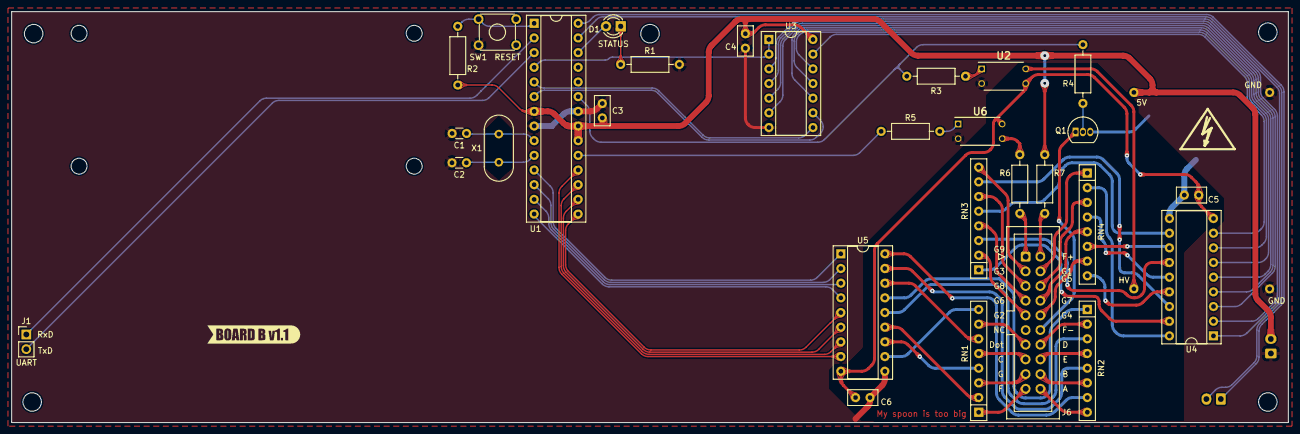
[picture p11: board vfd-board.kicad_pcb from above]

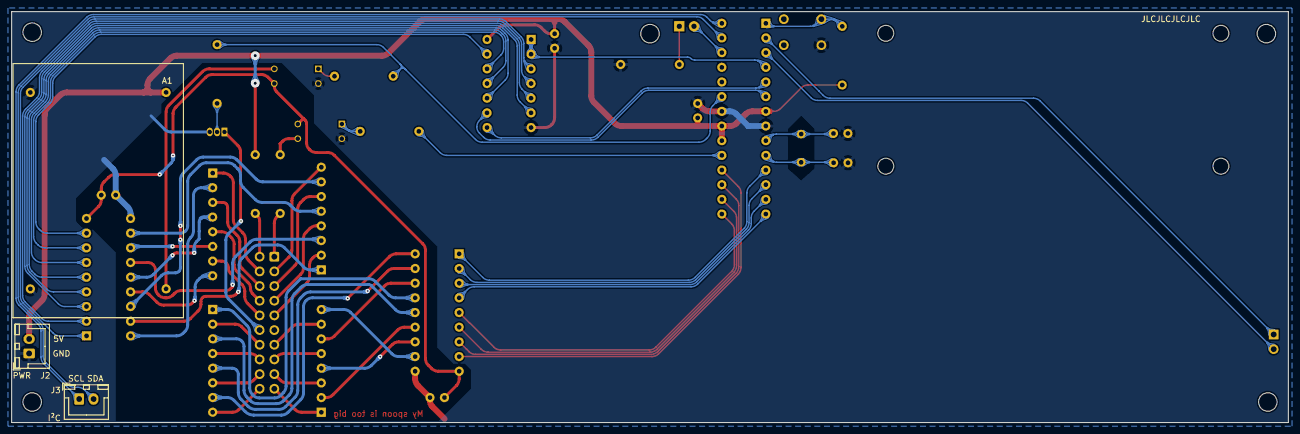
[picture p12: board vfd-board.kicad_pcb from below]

Board: 2 copper layers, 221.0 x 71.1 mm, 37 parts (3 on the bottom side), 73 nets.

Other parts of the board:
A2: Raspberry_Pi_Zero_Socketed_THT_FaceDown_MountingH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; Raspberry_Pi_Zero_Socketed_THT_FaceDown_MountingHoles
SYM_HV: Symbol_HighVoltage_Type2_CopperTop_VerySmall
kibuzzard-629EA45D: G***; kibuzzard-629EA45D
kibuzzard-6293E725: G***; kibuzzard-6293E725
kibuzzard-6293E830: G***; kibuzzard-6293E830

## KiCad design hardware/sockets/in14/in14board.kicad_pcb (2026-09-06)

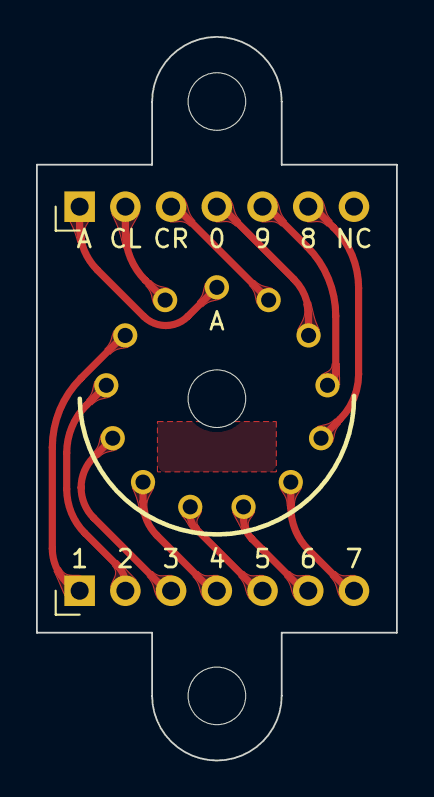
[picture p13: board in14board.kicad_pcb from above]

Board: 2 copper layers, 20.0 x 40.2 mm, 3 parts (0 on the bottom side), 13 nets.

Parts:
J1: IN-14; nixies-us-IN-14
J2: Out Back; PinHeader_1x07_P2.54mm_Vertical
J3: Out Front; PinHeader_1x07_P2.54mm_Vertical

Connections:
unnamed: J1.0, J2.4 (0)
unnamed: J1.1, J3.1
unnamed: J1.2, J3.2
unnamed: J1.3, J3.3
unnamed: J1.4, J3.4
unnamed: J1.5, J3.5
unnamed: J1.6, J3.6
unnamed: J1.7, J3.7
unnamed: J1.8, J2.6 (8)
unnamed: J1.9, J2.5 (9)
unnamed: J1.A, J2.1 (A)
unnamed: J1.LHDP (CL), J2.2 (CL)
unnamed: J1.RHDP (CR), J2.3 (CR)

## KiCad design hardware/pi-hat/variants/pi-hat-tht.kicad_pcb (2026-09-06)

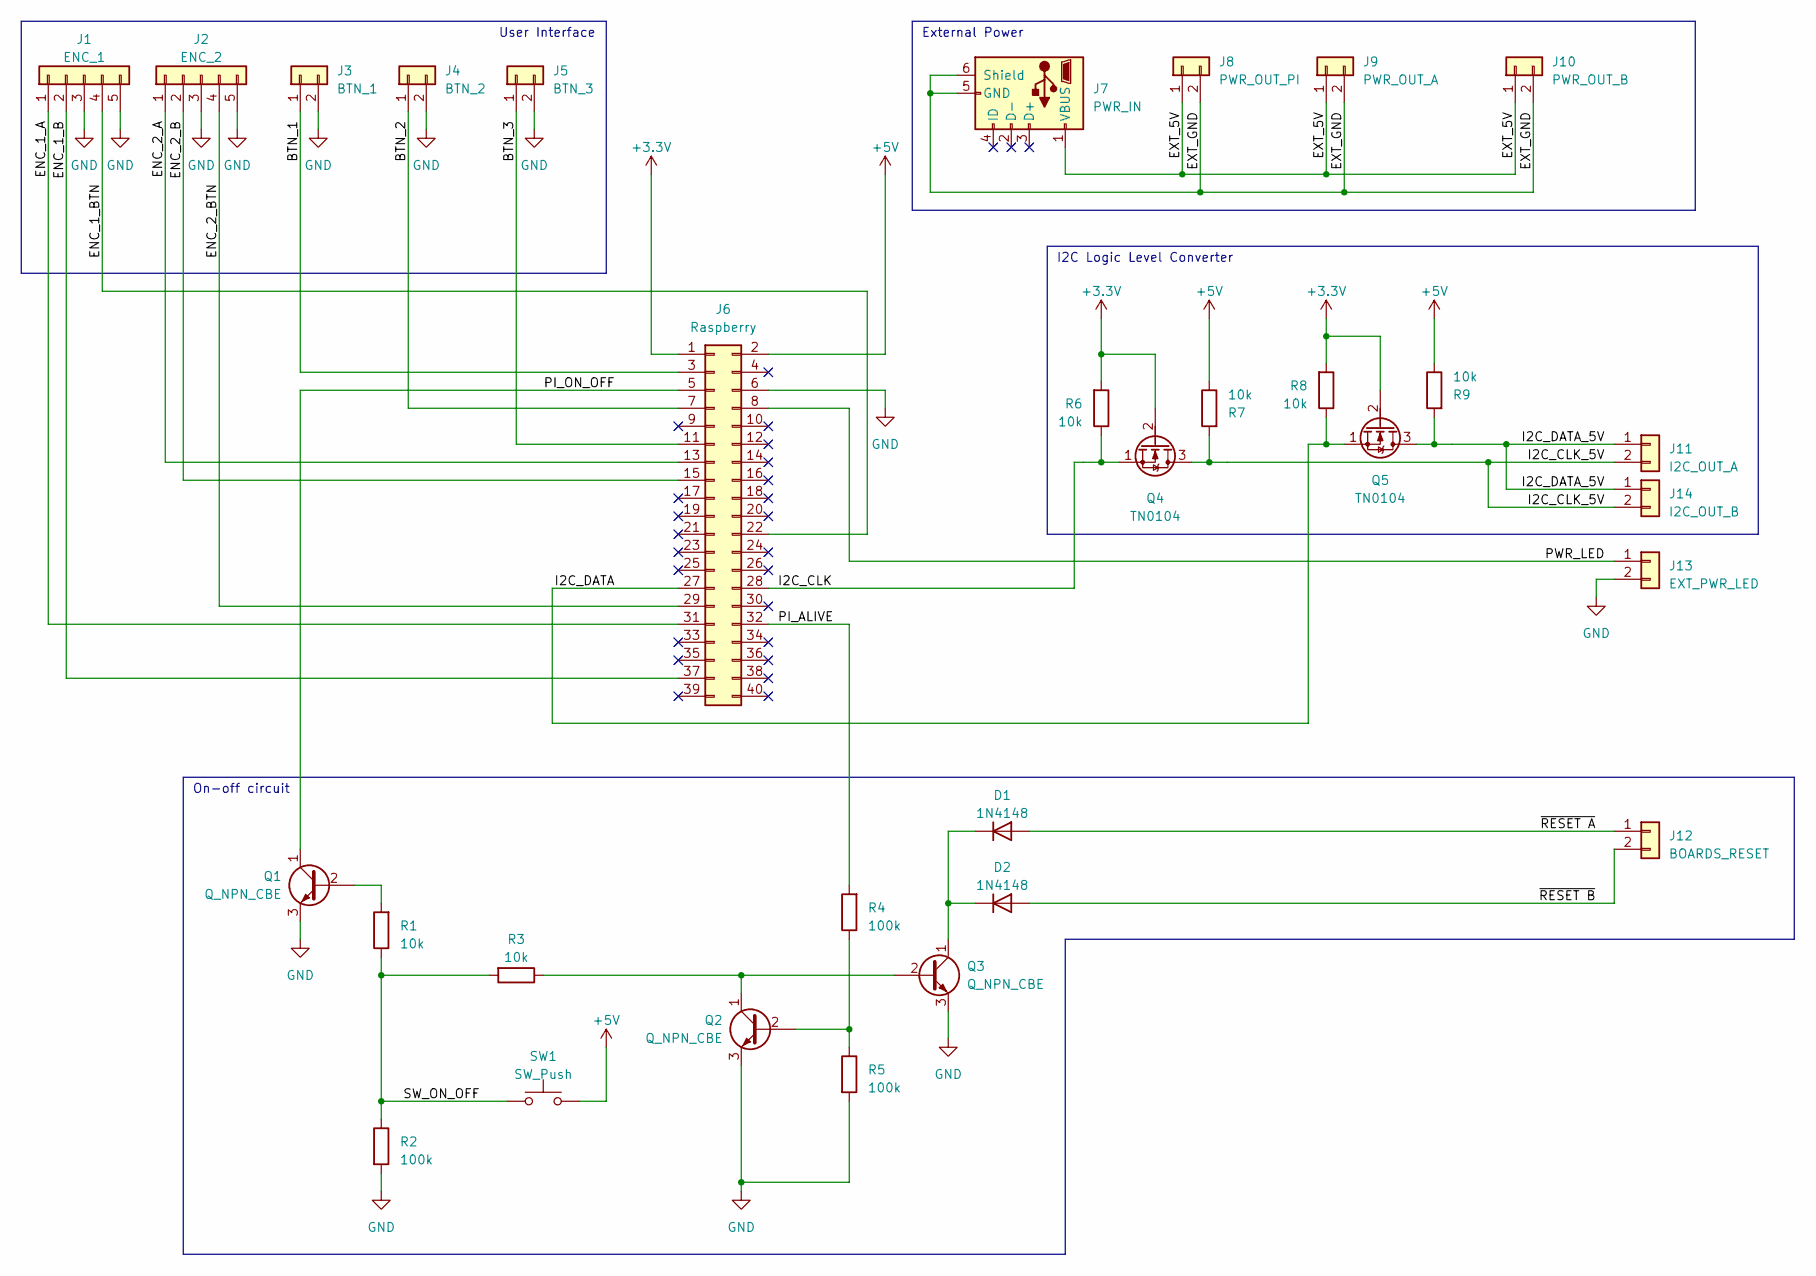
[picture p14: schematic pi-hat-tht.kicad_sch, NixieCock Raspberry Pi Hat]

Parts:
D1, D2: 1N4148; D_DO-34_SOD68_P7.62mm_Horizontal
J1: ENC_1; JST_XH_S5B-XH-A_1x05_P2.50mm_Horizontal
J2: ENC_2; JST_XH_S5B-XH-A_1x05_P2.50mm_Horizontal
J3: BTN_1; JST_XH_B2B-XH-A_1x02_P2.50mm_Vertical
J4: BTN_2; JST_XH_B2B-XH-A_1x02_P2.50mm_Vertical
J5: BTN_3; JST_XH_B2B-XH-A_1x02_P2.50mm_Vertical
J6: Raspberry; PinSocket_2x20_P2.54mm_Vertical
J7: PWR_IN; USB_Micro-B_Amphenol_10103594-0001LF_Horizontal
J8: PWR_OUT_PI; SolderWire-0.75sqmm_1x02_P4.8mm_D1.25mm_OD2.3mm
J9: PWR_OUT_A; JST_XH_B2B-XH-A_1x02_P2.50mm_Vertical
J10: PWR_OUT_B; JST_XH_B2B-XH-A_1x02_P2.50mm_Vertical
J11: I2C_OUT_A; JST_XH_B2B-XH-A_1x02_P2.50mm_Vertical
J12: BOARDS_RESET; JST_XH_B2B-XH-A_1x02_P2.50mm_Vertical
J13: EXT_PWR_LED; JST_XH_B2B-XH-A_1x02_P2.50mm_Vertical
J14: I2C_OUT_B; JST_XH_B2B-XH-A_1x02_P2.50mm_Vertical
Q1, Q2, Q3: Q_NPN_CBE; TO-92L_Inline
Q4, Q5: TN0104; TO-92L_Inline
R1, R3, R6, R7, R8, R9: 10k; R_Axial_DIN0207_L6.3mm_D2.5mm_P10.16mm_Horizontal
R2, R4, R5: 100k; R_Axial_DIN0207_L6.3mm_D2.5mm_P10.16mm_Horizontal
SW1: SW_Push; JST_XH_B2B-XH-A_1x02_P2.50mm_Vertical

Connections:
+3.3V: J6.1, Q4.2 (G), Q5.2 (G), R6.2, R8.2
+5V: J6.2, R7.1, R9.1, SW1.2
/BTN_1: J3.1, J6.3
/BTN_2: J4.1, J6.7
/BTN_3: J5.1, J6.11
/ENC_1_A: J1.1, J6.31
/ENC_1_B: J1.2, J6.37
/ENC_1_BTN: J1.4, J6.22
/ENC_2_A: J2.1, J6.13
/ENC_2_B: J2.2, J6.15
/ENC_2_BTN: J2.4, J6.29
/EXT_5V: J7.1 (VBUS), J8.1, J9.1, J10.1
/EXT_GND: J7.5 (GND), J7.6 (Shield), J8.2, J9.2, J10.2
/I2C_CLK: J6.28, Q4.1 (S), R6.1
/I2C_CLK_5V: J11.2, J14.2, Q4.3 (D), R7.2
/I2C_DATA: J6.27, Q5.1 (S), R8.1
/I2C_DATA_5V: J11.1, J14.1, Q5.3 (D), R9.2
/PI_ALIVE: J6.32, R4.2
/PI_ON_OFF: J6.5, Q1.1 (C)
/PWR_LED: J6.8, J13.1
/SW_ON_OFF: R1.1, R2.1, R3.2, SW1.1
/~RESET A: D1.2 (A), J12.1
/~RESET B: D2.2 (A), J12.2
GND: J1.3, J1.5, J2.3, J2.5, J3.2, J4.2, J5.2, J6.6, J13.2, Q1.3 (E), Q2.3 (E), Q3.3 (E), R2.2, R5.2
unnamed: D1.1 (K), D2.1 (K), Q3.1 (C)
unnamed: Q1.2 (B), R1.2
unnamed: Q2.2 (B), R4.1, R5.1
unnamed: Q2.1 (C), Q3.2 (B), R3.1

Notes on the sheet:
External Power
User Interface
On-off circuit
I2C Logic Level Converter

Board: 2 copper layers, 32 parts (1 on the bottom side), 28 nets, no tracks yet.

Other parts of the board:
A2: Raspberry_Pi_Zero_Socketed_THT_FaceDown_MountingH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; Raspberry_Pi_Zero_Socketed_THT_FaceDown_MountingHoles

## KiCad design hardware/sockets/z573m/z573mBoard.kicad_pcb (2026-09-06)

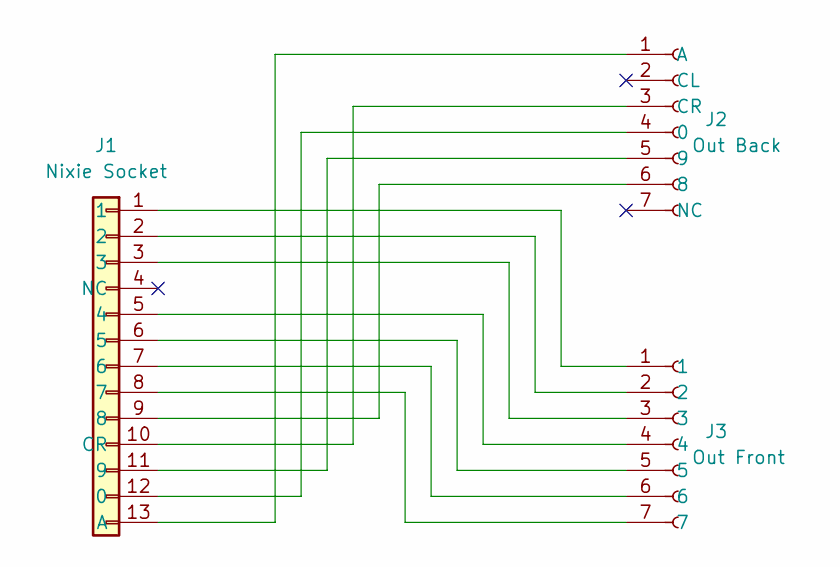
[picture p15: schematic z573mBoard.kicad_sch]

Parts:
J1: Nixie Socket; Z570M
J2: Out Back; PinHeader_1x07_P2.54mm_Vertical
J3: Out Front; PinHeader_1x07_P2.54mm_Vertical

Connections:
unnamed: J1.1, J3.1
unnamed: J1.2, J3.2
unnamed: J1.3, J3.3
unnamed: J1.5 (4), J3.4
unnamed: J1.6 (5), J3.5
unnamed: J1.7 (6), J3.6
unnamed: J1.8 (7), J3.7
unnamed: J1.9 (8), J2.6 (8)
unnamed: J1.10 (CR), J2.3 (CR)
unnamed: J1.11 (9), J2.5 (9)
unnamed: J1.12 (0), J2.4 (0)
unnamed: J1.13 (A), J2.1 (A)

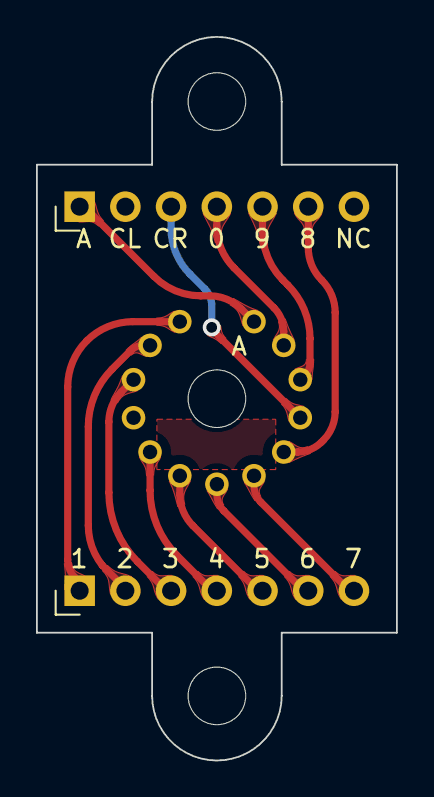
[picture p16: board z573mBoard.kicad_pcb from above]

Board: 2 copper layers, 20.0 x 40.2 mm, 3 parts (0 on the bottom side), 12 nets.

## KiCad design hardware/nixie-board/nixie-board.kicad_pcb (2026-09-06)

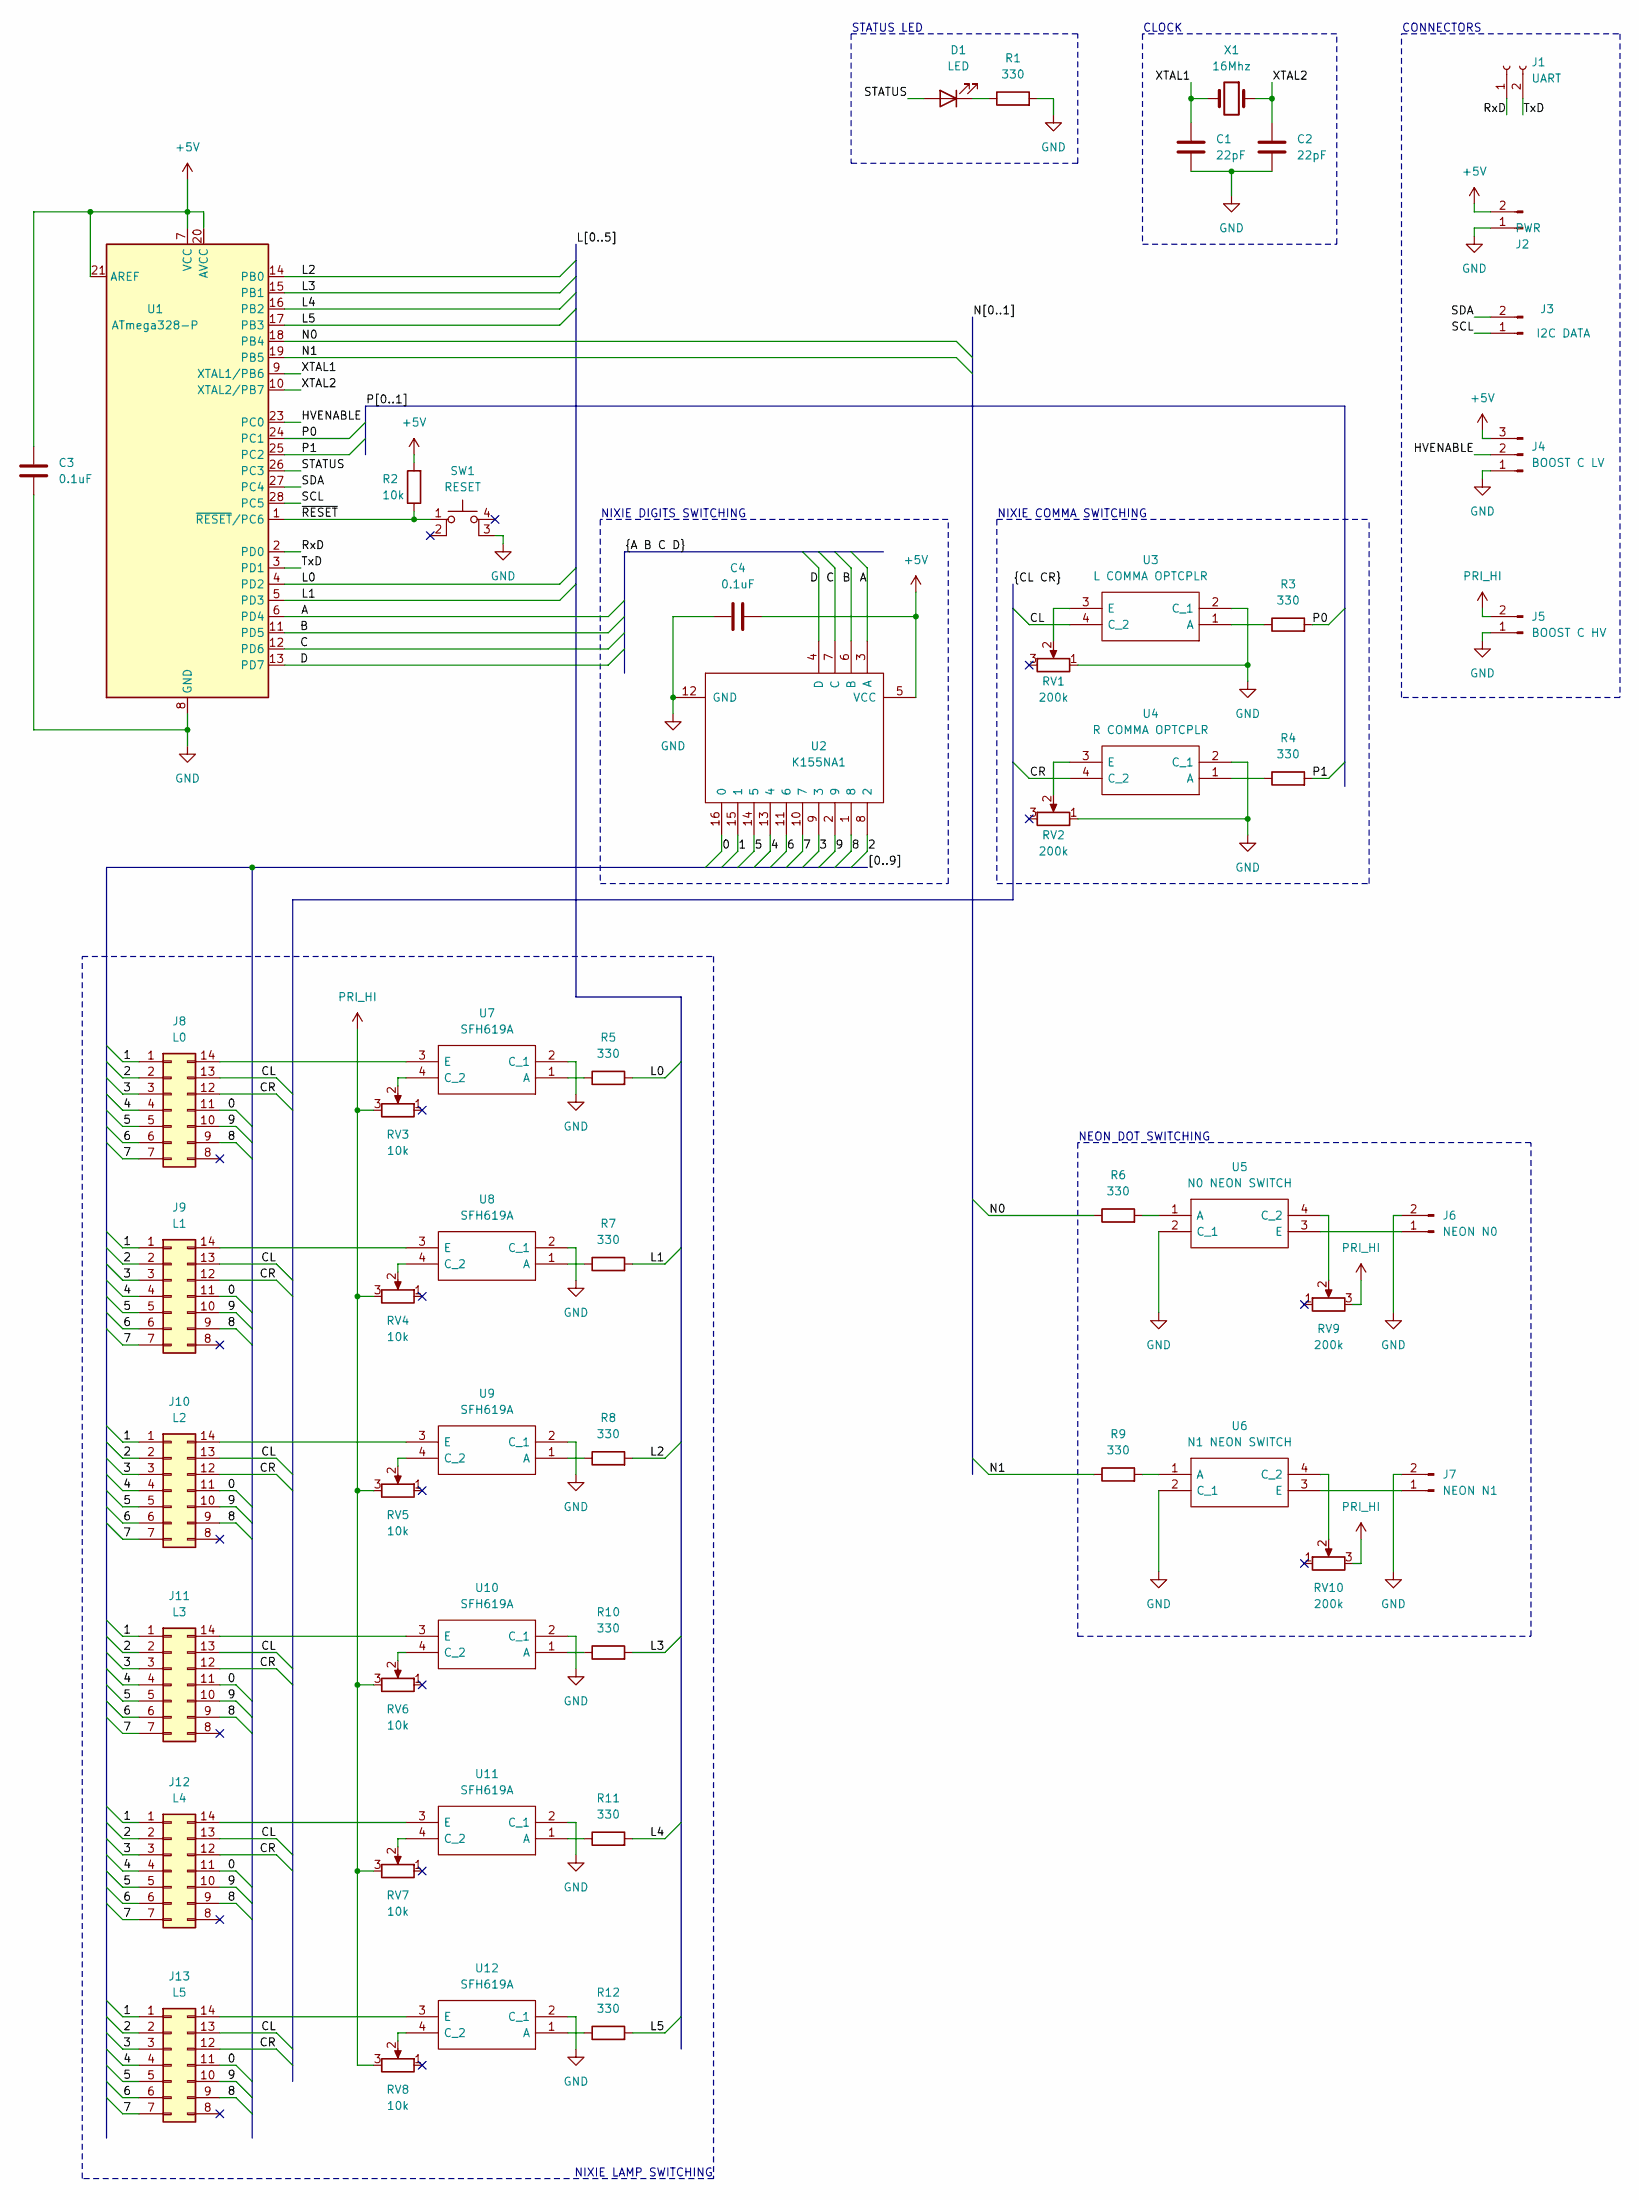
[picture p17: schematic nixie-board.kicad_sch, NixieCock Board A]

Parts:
C1, C2: 22pF; C_Disc_D3.0mm_W1.6mm_P2.50mm
C3, C4: 0.1uF; C_Disc_D5.0mm_W2.5mm_P2.50mm
D1: LED; LED_D3.0mm
J1: UART; PinHeader_1x02_P2.54mm_Vertical
J2: PWR; JST_XH_B2B-XH-A_1x02_P2.50mm_Vertical
J3: I2C DATA; JST_XH_B2B-XH-A_1x02_P2.50mm_Vertical
J4: BOOST C LV; JST_XH_B3B-XH-A_1x03_P2.50mm_Vertical
J5: BOOST C HV; JST_XH_B2B-XH-A_1x02_P2.50mm_Vertical
J6: NEON N0; JST_XH_B2B-XH-A_1x02_P2.50mm_Vertical
J7: NEON N1; JST_XH_B2B-XH-A_1x02_P2.50mm_Vertical
J8: L0; IDC-Header_2x07_P2.54mm_Vertical
J9: L1; IDC-Header_2x07_P2.54mm_Vertical
J10: L2; IDC-Header_2x07_P2.54mm_Vertical
J11: L3; IDC-Header_2x07_P2.54mm_Vertical
J12: L4; IDC-Header_2x07_P2.54mm_Vertical
J13: L5; IDC-Header_2x07_P2.54mm_Vertical
R1, R3, R4, R5, R6, R7, R8, R9, R10, R11, R12: 330; R_Axial_DIN0207_L6.3mm_D2.5mm_P10.16mm_Horizontal
R2: 10k; R_Axial_DIN0207_L6.3mm_D2.5mm_P10.16mm_Horizontal
RV1, RV2, RV9, RV10: 200k; Potentiometer_Bourns_3386F_Vertical
RV3, RV4, RV5, RV6, RV7, RV8: 10k; Potentiometer_Bourns_3386F_Vertical
SW1: RESET; SW_TH_Tactile_Omron_B3F-10xx
U1: ATmega328-P; DIP-28_W7.62mm
U2: K155NA1; DIP-16_W7.62mm
U3: L COMMA OPTCPLR; DIP762W56P254L469H470Q4N; Mouser Part Number 782-SFH619A
U4: R COMMA OPTCPLR; DIP762W56P254L469H470Q4N; Mouser Part Number 782-SFH619A
U5: N0 NEON SWITCH; DIP762W56P254L469H470Q4N; Mouser Part Number 782-SFH619A
U6: N1 NEON SWITCH; DIP762W56P254L469H470Q4N; Mouser Part Number 782-SFH619A
U7, U8, U9, U10, U11, U12: SFH619A; DIP762W56P254L469H470Q4N; Mouser Part Number 782-SFH619A
X1: 16Mhz; Crystal_HC49-4H_Vertical

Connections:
+5V: C3.1, C4.2, J2.2, J4.3, R2.2, U1.7 (VCC), U1.20 (AVCC), U1.21 (AREF), U2.5 (VCC)
/0: J8.11 (0), J9.11 (0), J10.11 (0), J11.11 (0), J12.11 (0), J13.11 (0), U2.16 (0)
/1: J8.1, J9.1, J10.1, J11.1, J12.1, J13.1, U2.15 (1)
/2: J8.2, J9.2, J10.2, J11.2, J12.2, J13.2, U2.8 (2)
/3: J8.3, J9.3, J10.3, J11.3, J12.3, J13.3, U2.9 (3)
/4: J8.4, J9.4, J10.4, J11.4, J12.4, J13.4, U2.13 (4)
/5: J8.5, J9.5, J10.5, J11.5, J12.5, J13.5, U2.14 (5)
/6: J8.6, J9.6, J10.6, J11.6, J12.6, J13.6, U2.11 (6)
/7: J8.7, J9.7, J10.7, J11.7, J12.7, J13.7, U2.10 (7)
/8: J8.9 (8), J9.9 (8), J10.9 (8), J11.9 (8), J12.9 (8), J13.9 (8), U2.1 (8)
/9: J8.10 (9), J9.10 (9), J10.10 (9), J11.10 (9), J12.10 (9), J13.10 (9), U2.2 (9)
/A: U1.6 (PD4), U2.3 (A)
/B: U1.11 (PD5), U2.6 (B)
/C: U1.12 (PD6), U2.7 (C)
/CL: J8.13 (CL), J9.13 (CL), J10.13 (CL), J11.13 (CL), J12.13 (CL), J13.13 (CL), U3.4 (C_2)
/CR: J8.12 (CR), J9.12 (CR), J10.12 (CR), J11.12 (CR), J12.12 (CR), J13.12 (CR), U4.4 (C_2)
/D: U1.13 (PD7), U2.4 (D)
/HVENABLE: J4.2, U1.23 (PC0)
/L0: R5.2, U1.4 (PD2)
/L1: R7.2, U1.5 (PD3)
/L2: R8.2, U1.14 (PB0)
/L3: R10.2, U1.15 (PB1)
/L4: R11.2, U1.16 (PB2)
/L5: R12.2, U1.17 (PB3)
/N0: R6.1, U1.18 (PB4)
/N1: R9.1, U1.19 (PB5)
/P0: R3.2, U1.24 (PC1)
/P1: R4.2, U1.25 (PC2)
/RxD: J1.1, U1.2 (PD0)
/SCL: J3.1, U1.28 (PC5)
/SDA: J3.2, U1.27 (PC4)
/STATUS: D1.2 (A), U1.26 (PC3)
/TxD: J1.2, U1.3 (PD1)
/XTAL1: C1.1, U1.9 (XTAL1/PB6), X1.2
/XTAL2: C2.1, U1.10 (XTAL2/PB7), X1.1
/~RESET: R2.1, SW1.1, U1.1 (~RESET/PC6)
GND: C1.2, C2.2, C3.2, C4.1, J2.1, J4.1, J5.1 (HV), J6.2, J7.2, R1.2, RV1.1, RV2.1, SW1.3 (K), U1.8 (GND), U1.22 (GND), U2.12 (GND), U3.2 (C_1), U4.2 (C_1), U5.2 (C_1), U6.2 (C_1), U7.2 (C_1), U8.2 (C_1), U9.2 (C_1), U10.2 (C_1), U11.2 (C_1), U12.2 (C_1)
unnamed: D1.1 (K), R1.1
unnamed: J6.1, U5.3 (E)
unnamed: J7.1, U6.3 (E)
unnamed: J8.14 (Anode), U7.3 (E)
unnamed: J9.14 (Anode), U8.3 (E)
unnamed: J10.14 (Anode), U9.3 (E)
unnamed: J11.14 (Anode), U10.3 (E)
unnamed: J12.14 (Anode), U11.3 (E)
unnamed: J13.14 (Anode), U12.3 (E)
unnamed: R3.1, U3.1 (A)
unnamed: R4.1, U4.1 (A)
unnamed: R5.1, U7.1 (A)
unnamed: R6.2, U5.1 (A)
unnamed: R7.1, U8.1 (A)
unnamed: R8.1, U9.1 (A)
unnamed: R9.2, U6.1 (A)
unnamed: R10.1, U10.1 (A)
unnamed: R11.1, U11.1 (A)
unnamed: R12.1, U12.1 (A)
unnamed: RV1.2, U3.3 (E)
unnamed: RV2.2, U4.3 (E)
unnamed: RV3.2, U7.4 (C_2)
unnamed: RV4.2, U8.4 (C_2)
unnamed: RV5.2, U9.4 (C_2)
unnamed: RV6.2, U10.4 (C_2)
unnamed: RV7.2, U11.4 (C_2)
unnamed: RV8.2, U12.4 (C_2)
unnamed: RV9.2, U5.4 (C_2)
unnamed: RV10.2, U6.4 (C_2)
PRI_HI: J5.2, RV3.3, RV4.3, RV5.3, RV6.3, RV7.3, RV8.3, RV9.3, RV10.3

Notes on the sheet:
NIXIE DIGITS SWITCHING
NIXIE LAMP SWITCHING
NEON DOT SWITCHING
NIXIE COMMA SWITCHING
STATUS LED
CONNECTORS
CLOCK

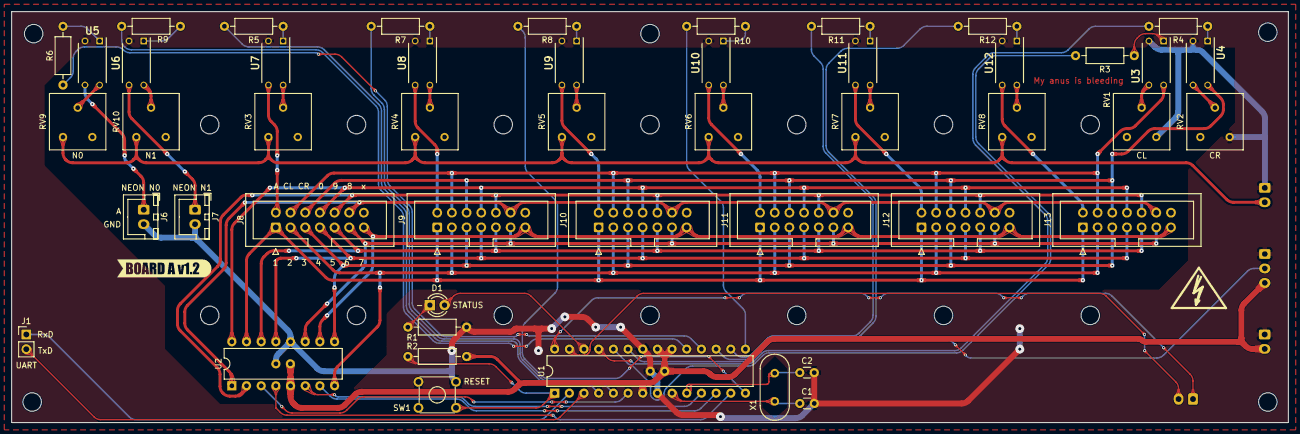
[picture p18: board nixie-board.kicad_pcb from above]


Board: 2 copper layers, 221.0 x 71.1 mm, 58 parts (6 on the bottom side), 67 nets.

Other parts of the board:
SYM_HV: Symbol_HighVoltage_Type2_CopperTop_VerySmall
kibuzzard-629EA4E7: G***; kibuzzard-629EA4E7
kibuzzard-6293E725: G***; kibuzzard-6293E725
kibuzzard-6293E830: G***; kibuzzard-6293E830

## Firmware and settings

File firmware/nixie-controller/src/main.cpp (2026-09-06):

#include <Arduino.h>
#include <Wire.h>

//TODO: add command to run intro
//TODO: include code execution in the waits (is it worth it?) or at least the interrupts?
//DONE: measure elapsed frame time and subtract from bright/dim waits (is it worth it?)
//TODO: instead of "manual" gradual dimming, include ready routines for it and commands to trigger them (is it really needed?)
//TODO: think about improving points dimming (is it possible?)
//TODO: think about pull-downs on anodes & maybe shorter AFTER_IMAGE_US thanks to that?
//TODO: think about testing PWM dimming (each anode on a PWM output) using PWM registers with no clock divider (at max freq) (is it worth it?)

//DONE: support HV circuit switching (command)
//DONE: support commas
//DONE: 2-6 digits support

//you can change this to adjust the code to the physical display length (values 2-6 are allowed)
const unsigned short DIGITS_USED = 6;

//don't change this:
const unsigned short MAX_DIGITS_USED = 6;

//number commands - last 4 bits set the number, anything above 9 is no light at all on the lamp
//REMEMBER - all CMDs within <0x80 - 0xD0> are treated as a number command - so don't use those for other purposes!
const byte CMD_NUM = 0x80;

//regular commands
const byte CMD_OFF = 0x10; //turn the lamps off
const byte CMD_ON = 0x11; //turn the lamps on
const byte CMD_INTRO_ON = 0x12; //turn the intro on
const byte CMD_FIN = 0x20; //loads number and dimming values from buffers to output (renders new frame)
const byte CMD_NOOP = 0x30;
const byte CMD_START = 0x40; //currently unused - works as NOOP
const byte CMD_POINT = 0x50; //last 4 bits determine which point should be turned on (only values 0 and 1 are allowed)
const byte CMD_DIMMER = 0x60; //last 4 bits set the duty cycle; it's assigned to the latest digit set
const byte CMD_LAMP_POINT_L = 0xE0; //last 4 bits determine which left comma should be on (only values between 0 and DIGITS_USED - 1 are allowed)
const byte CMD_LAMP_POINT_R = 0xF0; //last 4 bits determine which right comma should be on (only values between 0 and DIGITS_USED - 1 are allowed)

//responses
const byte RESP_SUCCESS = 0x00;
const byte RESP_FAIL = 0b01010101;

//pins
const byte OUT_BCD[] = {4,5,6,7}; //pins for encoding currently displayed number (in BCD)
const byte OUT_POINTS[] = {12,13}; //pins for setting decimal points (neon lamps)
//array size must equal MAX_DIGITS_USED
const byte OUT_ANODES[] = {2,3,8,9,10,11}; //pins for multiplexing lamps (they switch power to particular anodes)
const byte OUT_LAMP_COMMAS[] = {A1, A2}; //pins for decimal points in main lamps
const byte HV_ENABLE = A0;
const byte STATUS = A3;

//times
//Afterimage occurs below 300 us
const unsigned short AFTER_IMAGE_US = 300; //interframe interval to avoid afterimages
const unsigned short FRAME_US = 1000; //frame time
const float DIMMING_CURVE_POWER = 2.1;

//values
const byte LAMP_OFF = 15;

//buffers & other globals
//TODO: should these be volatile? it triggers warnings...
bool point_vals[2] = {false, false};
bool point_vals_buffer[2] = {false, false};
bool points_off[2] = {false, false};

//array sizes must equal MAX_DIGITS_USED
bool commas_off[MAX_DIGITS_USED] = {false,false,false,false,false,false};
bool l_comma_vals[MAX_DIGITS_USED] = {false,false,false,false,false,false};
bool l_comma_vals_buffer[MAX_DIGITS_USED] = {false,false,false,false,false,false};
bool r_comma_vals[MAX_DIGITS_USED] = {false,false,false,false,false,false};
bool r_comma_vals_buffer[MAX_DIGITS_USED] = {false,false,false,false,false,false};

//array sizes must equal MAX_DIGITS_USED
byte nums[MAX_DIGITS_USED] = {0, 0, 0, 0, 0, 0};
byte nums_buffer[MAX_DIGITS_USED] = {15, 15, 15, 15, 15, 15};
byte fail_nums[MAX_DIGITS_USED] = {15, 15, 15, 15, 15, 15};

//array sizes must equal MAX_DIGITS_USED
unsigned short bright_times[] = {FRAME_US,FRAME_US,FRAME_US,FRAME_US,FRAME_US,FRAME_US};
unsigned short dim_times[] = {0,0,0,0,0,0};
byte dimmer_buffer[] = {15,15,15,15,15,15};
byte dimmer_defaults[] = {15,15,15,15,15,15};

byte curr_lamp_idx = 0;
byte curr_l_point_idx = 0;
byte curr_r_point_idx = 0;

volatile bool new_frame = false;

//in the beginning, intro is on
bool intro_mode = true;

//debug
unsigned long current_frame_no = 0;

/**
 * Renders given number
 */
void numOut( byte num )
{
    for (byte i = 0; i < 4; i++) {
        digitalWrite( OUT_BCD[i], ( num & ( 1 << i ) ) != 0 );
    }
}

/**
 * Multiplexes one lamp
 */
void multiplexDigit(byte anode_idx)
{
    bool show_num = (nums[anode_idx] >= 0) && (nums[anode_idx] < 10);
    //points are multiplexed together with anode 0 and 1:
    bool show_point = (anode_idx == 0 || anode_idx == 1) && point_vals[anode_idx];

    bool show_l_comma = l_comma_vals[anode_idx];
    bool show_r_comma = r_comma_vals[anode_idx];

    unsigned long numProcessHighStart = micros();
    if (show_l_comma) {
        digitalWrite(OUT_LAMP_COMMAS[0], HIGH);
    }
    if (show_r_comma) {
        digitalWrite(OUT_LAMP_COMMAS[1], HIGH);
    }
    if (show_num) {
        numOut(nums[anode_idx]); //important NOT to set the numOut when there's no need - at high framerates it confuses the russian and causes microblinks on the off lamp
        digitalWrite(OUT_ANODES[anode_idx], HIGH );
    }
    if (show_point) {
        digitalWrite(OUT_POINTS[anode_idx], HIGH );
    }
    unsigned long numProcessHighEnd = micros();

    //variable delay to compensate for unpredictable duration of the section above
    unsigned int final_delay = (bright_times[anode_idx]) - (numProcessHighEnd - numProcessHighStart);
    if (final_delay > bright_times[anode_idx]) { //a way to check < 0 (unsigned numbers!) - both for overflow & too long processing
        final_delay = 1;
    }
    delayMicroseconds(final_delay);


    unsigned long numProcessLowStart = micros();
    if (show_num) {
        digitalWrite(OUT_ANODES[anode_idx], LOW );
    }
    if (show_point) {
        digitalWrite(OUT_POINTS[anode_idx], LOW );
    }
    if (show_l_comma) {
        digitalWrite(OUT_LAMP_COMMAS[0], LOW);
    }
    if (show_r_comma) {
        digitalWrite(OUT_LAMP_COMMAS[1], LOW);
    }
    unsigned long numProcessLowEnd = micros();

    //variable delay to compensate for unpredictable duration of the section above
    final_delay = (dim_times[anode_idx]) - (numProcessLowEnd - numProcessLowStart);
    if (final_delay > dim_times[anode_idx]) { //a way to check < 0 (unsigned numbers!) - both for overflow & too long processing
        final_delay = 1;
    }
    delayMicroseconds(final_delay);
}

void setupIntroValues()
{
    unsigned short frames_60 = 10;
    unsigned short frames_2digs = 50;
    unsigned short frames_2 = 300;

    if (point_vals[0] == point_vals[1]) {
        point_vals[0] = !point_vals[1];
    }
    if (current_frame_no % 100 == 0) {
        point_vals[0] = !point_vals[0];
        point_vals[1] = !point_vals[1];
    }

    for (byte j = 0; j < DIGITS_USED; j++) {
        //right commas looped sweep
        if (current_frame_no % (DIGITS_USED * frames_60) == j * frames_60) {
            for (byte k = 0; k < DIGITS_USED; k++) {
                if (k == j) {
                    r_comma_vals[k] = true;
                } else {
                    r_comma_vals[k] = false;
                }
            }
        }
        //numbers on one by one
        if ((current_frame_no >= j * frames_2digs) && (current_frame_no % 10 == 0)) {
            nums[j] = random() % 10;
        }
        //brightness gradual up
        float booblator = (float)(current_frame_no - j * frames_2digs);
        if (booblator < 1)
            booblator = 1.0;
        else if (booblator > (float)frames_2)
            booblator = (float)frames_2;
        float multiplier = pow(booblator/(float)frames_2, 2.5);
        bright_times[j] = multiplier * FRAME_US;
        dim_times[j] = (1.0 - multiplier) * FRAME_US;
    }
}

/**
 * Actual command handling
 */
byte handleInput (byte in_byte)
{
    //we received a command, so we're serious now...
    intro_mode = false;

    if ((in_byte & 0xF0) == CMD_START) {
        //unused now - same as NOOP
        return RESP_SUCCESS;
    }
    if (in_byte == CMD_ON) {
        digitalWrite(HV_ENABLE, HIGH);

        return RESP_SUCCESS;
    }
    if (in_byte == CMD_OFF) {
        digitalWrite(HV_ENABLE, LOW);

        return RESP_SUCCESS;
    }
    if (in_byte == CMD_INTRO_ON) {
        //...except if we don't want to be serious
        intro_mode = true;

        return RESP_SUCCESS;
    }
    if ((in_byte & 0xF0) == CMD_LAMP_POINT_L) {
        curr_l_point_idx = in_byte & 0x0F;
        if (curr_l_point_idx >= DIGITS_USED) {
            //digit above the number of digits used is not allowed
            return RESP_FAIL;
        }

        l_comma_vals_buffer[curr_l_point_idx] = true;

        return RESP_SUCCESS;
    }
    if ((in_byte & 0xF0) == CMD_LAMP_POINT_R) {
        curr_r_point_idx = in_byte & 0x0F;
        if (curr_r_point_idx >= DIGITS_USED) {
            //digit above the number of digits used is not allowed
            return RESP_FAIL;
        }

        r_comma_vals_buffer[curr_r_point_idx] = true;

        return RESP_SUCCESS;
    }
    if (in_byte & CMD_NUM) {  //a number was sent
        curr_lamp_idx = (in_byte & 0x70) >> 4;
        if (curr_lamp_idx >= DIGITS_USED) {
            //digit above the number of digits used is not allowed
            return RESP_FAIL;
        }

        nums_buffer[curr_lamp_idx] = in_byte & 0x0F;

        return RESP_SUCCESS;
    }
    if ((in_byte & 0xF0) == CMD_FIN) {
        new_frame = true;

        return RESP_SUCCESS;
    }
    if ((in_byte & 0xF0) == CMD_NOOP) {
        return RESP_SUCCESS;
    }
    if ((in_byte & 0xF0) == CMD_POINT) {
        byte point_idx = in_byte & 0x0F;
        if (point_idx < 0 || point_idx > 1) {
            return RESP_FAIL;
        }

        point_vals_buffer[point_idx] = true;

        return RESP_SUCCESS;
    }
    if ((in_byte & 0xF0) == CMD_DIMMER) {
        dimmer_buffer[curr_lamp_idx] = in_byte & 0x0F;

        //if dimming set to 0, shut the lamp off completely
        if (!dimmer_buffer[curr_lamp_idx]) {
            nums_buffer[curr_lamp_idx] = LAMP_OFF;
        }

        return RESP_SUCCESS;
    }

    return RESP_FAIL;
}

/**
 * Handles incoming message event
 */
void receiveEvent(int howMany)
{
    while(Wire.available()) // loop through all
    {
        byte c = Wire.read(); // receive byte
        handleInput(c); //return it?
    }
}

void handleNewFrame()
{
    memcpy(point_vals, point_vals_buffer, 2*sizeof(bool));
    memcpy(point_vals_buffer, points_off, 2*sizeof(bool));
    memcpy(nums, nums_buffer,MAX_DIGITS_USED*sizeof(byte));
    memcpy(nums_buffer, fail_nums, MAX_DIGITS_USED*sizeof(byte));
    memcpy(l_comma_vals, l_comma_vals_buffer,MAX_DIGITS_USED*sizeof(byte));
    memcpy(l_comma_vals_buffer, commas_off, MAX_DIGITS_USED*sizeof(byte));
    memcpy(r_comma_vals, r_comma_vals_buffer,MAX_DIGITS_USED*sizeof(byte));
    memcpy(r_comma_vals_buffer, commas_off, MAX_DIGITS_USED*sizeof(byte));
    for (byte i = 0; i < MAX_DIGITS_USED; i++) {
        float multiplier = pow( (float)(dimmer_buffer[i] + 1)/16.0, DIMMING_CURVE_POWER );
        bright_times[i] =(short) ((float)FRAME_US * multiplier);
        dim_times[i] = (short) ((float)FRAME_US * ( 1 - multiplier ));
    }
    memcpy(dimmer_buffer, dimmer_defaults, MAX_DIGITS_USED*sizeof(byte));
    curr_lamp_idx = 0;
}

//silly - pauses lamps
//void statusBlink(int count = 1) {
//    for (int i = 0; i < count; i++) {
//        digitalWrite(STATUS, LOW);
//        delay(100);
//        digitalWrite(STATUS, HIGH);
//        delay(100);
//    }
//}

void debugSetABunchOfNumbers() {
    handleInput(CMD_START);
    handleInput(CMD_NUM | 0x00 | 1);
//    handleInput(CMD_DIMMER | 2);
    handleInput(CMD_NUM | 0x10 | 2);
//    handleInput(CMD_DIMMER | 2);
    handleInput(CMD_NUM | 0x20 | 3);
//    handleInput(CMD_DIMMER | 2);
    handleInput(CMD_NUM | 0x30 | 4);
//    handleInput(CMD_DIMMER | 2);
    handleInput(CMD_NUM | 0x40 | 5);
//    handleInput(CMD_DIMMER | 2);
    handleInput(CMD_NUM | 0x50 | 6);
//    handleInput(CMD_DIMMER | 2);
    handleInput(CMD_POINT | 0);
    handleInput(CMD_LAMP_POINT_R | 2);
    handleInput(CMD_LAMP_POINT_L | 2);
    handleInput(CMD_FIN);
}

void setup() {
    //status led init
    pinMode(STATUS, OUTPUT);
    digitalWrite(STATUS, LOW);

    //lamps init
    for (byte i = 0; i < MAX_DIGITS_USED; i++) {
        pinMode( OUT_ANODES[i], OUTPUT );
        digitalWrite( OUT_ANODES[i], LOW );
        nums[i] = 15;
    }

    //lamp points init
    for (byte i = 0; i < 2; i++) {
        pinMode(OUT_LAMP_COMMAS[i], OUTPUT );
        digitalWrite(OUT_LAMP_COMMAS[i], LOW );
    }

    //digits init
    for (byte i = 0; i < 4; i++) {
        pinMode( OUT_BCD[i], OUTPUT );
        digitalWrite( OUT_BCD[i], LOW );
    }

    //decimal points init
    for (byte i = 0; i < 2; i++) {
        pinMode( OUT_POINTS[i], OUTPUT );
        digitalWrite( OUT_POINTS[i], LOW );
    }

    //power init
    delay(100);
    pinMode(HV_ENABLE, OUTPUT);
    digitalWrite(HV_ENABLE, HIGH);
    digitalWrite(STATUS, HIGH);

    //communications init
    Wire.begin(0x4); // TODO: move the address to a const
    Wire.onReceive(receiveEvent); // register event

    Serial.begin(115200);

//    statusBlink(2);
    Serial.println("hullo");

    //debug
//    debugSetABunchOfNumbers();
//    handleInput(CMD_OFF);
}

void loop() {

    if (intro_mode) {
        setupIntroValues();
    }

    //digits & points on-off
    for (unsigned short i = 0; i < DIGITS_USED - 1; i++) {
        multiplexDigit(i);
        delayMicroseconds(AFTER_IMAGE_US); //Afterimage occurs below 300 us
    }
    //last digit treated separately due to adaptive delay afterwards
    multiplexDigit(DIGITS_USED - 1);

    unsigned long newFrameProcessStart = micros();
    if (new_frame) {
        handleNewFrame();
        new_frame = false;
    }
    unsigned long newFrameProcessEnd = micros();

    //variable delay to compensate for unpredictable duration of the above section (happens only sometimes)
    unsigned short lastDelay = AFTER_IMAGE_US - (newFrameProcessEnd - newFrameProcessStart);
    if (lastDelay > AFTER_IMAGE_US) { //a way of checking if < 0 (it's unsigned!) - both for overflow and for too long duration above
        lastDelay = 1;
    }
    delayMicroseconds(lastDelay);

    //debug
    current_frame_no++;
}

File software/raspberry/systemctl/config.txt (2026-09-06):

# For more options and information see
# http://rpf.io/configtxt
# Some settings may impact device functionality. See link above for details

# uncomment if you get no picture on HDMI for a default "safe" mode
#hdmi_safe=1

# uncomment this if your display has a black border of unused pixels visible
# and your display can output without overscan
#disable_overscan=1

# uncomment the following to adjust overscan. Use positive numbers if console
# goes off screen, and negative if there is too much border
#overscan_left=16
#overscan_right=16
#overscan_top=16
#overscan_bottom=16

# uncomment to force a console size. By default it will be display's size minus
# overscan.
#framebuffer_width=1280
#framebuffer_height=720

# uncomment if hdmi display is not detected and composite is being output
#hdmi_force_hotplug=1

# uncomment to force a specific HDMI mode (this will force VGA)
#hdmi_group=1
#hdmi_mode=1

# uncomment to force a HDMI mode rather than DVI. This can make audio work in
# DMT (computer monitor) modes
#hdmi_drive=2

# uncomment to increase signal to HDMI, if you have interference, blanking, or
# no display
#config_hdmi_boost=4

# uncomment for composite PAL
#sdtv_mode=2

#uncomment to overclock the arm. 700 MHz is the default.
#arm_freq=800

# Uncomment some or all of these to enable the optional hardware interfaces
#dtparam=i2c_arm=on
#dtparam=i2s=on
dtparam=spi=off

# Uncomment this to enable infrared communication.
#dtoverlay=gpio-ir,gpio_pin=17
#dtoverlay=gpio-ir-tx,gpio_pin=18

# Additional overlays and parameters are documented /boot/overlays/README

# Enable audio (loads snd_bcm2835)
#dtparam=audio=on


[pi4]
# Enable DRM VC4 V3D driver on top of the dispmanx display stack
dtoverlay=vc4-fkms-v3d
max_framebuffers=2

[all]
gpio=12=op,dh
#gpio=26=op,dl
#gpio=16,6,25=op,dl
#gpio=5=op,dh

#dtoverlay=vc4-fkms-v3d

#dtparam=act_led_trigger=actpwr

#dtparam=act_led_trigger=default-on
#dtoverlay=act-led,activelow=off,gpio=12

#not supported?
#dtoverlay=gpio-led,gpio=12,label=resetlamps,trigger=default-on,active_low=0

start_x=0

dtoverlay=gpio-shutdown

#dtoverlay=i2c-gpio,i2c_gpio_sda=30,i2c_gpio_scl=31,bus=3
#dtoverlay=i2c0,pins_0_1
dtparam=i2c_vc=on

#"power led"
enable_uart=1
#dtparam=act_led_gpio=14

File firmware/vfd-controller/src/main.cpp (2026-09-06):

#include <Arduino.h>

#include "../lib/IV18Display/IV18Display.h"
#include "../lib/I2CComms/I2CComms.h"
#include "../lib/IV18Display/IV18Animator.h"
#include "../lib/AnimatorFailureListener/IV18AnimatorSerialFailureListener.h"

const byte I2C_ADDR = 0x5;

IV18Animator* animator;
AnimatorFailureListenerInterface* animatorFailureListener;

long currentFrame = 0;

void setup()
{
    Serial.begin(115200);
    Serial.println("yo");

    animator = new IV18Animator(&Display);
    I2CComms::init(I2C_ADDR);

    // TODO: use this for animation timing debug
//    animatorFailureListener = new IV18AnimatorSerialFailureListener(animator);

    // TODO: enable it by command, not here! Or disable by command?
//    delay(100);
    Display.on();

    // run intro in the beginning
    I2CComms::addCommandToWriteBuffer(IV18I2CCommandExecutor::CMD_INTRO_ON);
}

void loop()
{
    // TODO: disable interrupts here? would omit packets?

    // run a frame of the basic animation
    animator->doFrame();

    // run high-level animation sequencing if applicable (e.g. if intro is on)
    animator->doCurrentSequencing();
}

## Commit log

2021-04-10 failed dimming idea removed
    [main.cpp]
2021-04-18 displaying currentString
2021-04-21 I2C communication testing scripts for nixie
2022-08-21 grid9 support, some fixes TODO wait after GRID9
    [main.cpp]
2023-01-25 animator merging threads
2023-01-25 lil refac + proper frame length fix
    [main.cpp]
2023-01-25 prepare enabling step changes between frames
2023-01-25 passing thread steps + grid animation refac WIP
2023-01-26 phantom big comma caused by bad idx type... fixed
    [main.cpp]
2023-01-26 unnecessary empty frame removed
2023-01-26 thread pointers instead of step array pointers
2023-01-27 generalized sinusoidal duty cycle gen + warning status led cycle
2023-01-27 led warning, more detailed text warning WIP TODO why actual 0??
2023-01-27 fail listener cleanup, animation retiming
    [main.cpp]
2023-01-29 more groundwork for grid dimming
2023-02-03 fixed last digit animation - separate cooldown for digit9 switch
    [main.cpp]
2023-02-03 nicer animation; sillier text; todo; micro fix
    [main.cpp]
2023-02-04 grid9 cooldown reduced after adding a pull-down resistor
2023-02-05 i2c commands buffering seems done
2023-02-05 commands prototype WIP
2023-03-07 DeviceAnimator constructor
2023-03-07 some fixes + a new way to run animation step callback
    [main.cpp]
2023-03-07 some renames, led animation refac, square heartbeat
2023-03-07 commands to set led modes
2023-03-12 raspberry boot/config files
    [config.txt]
2023-03-12 sending current mode to vfd
2023-04-09 power led
    [config.txt]
2023-04-09 poisoning prevention + whitespace
    [doStuff.py]
2023-04-24 intervals after i2c commands
2023-04-24 silly method name fixed
    [piToVFD.py]
2023-08-15 pausing i2c during buffer swap+read (doesn't help...)
2023-08-17 board schematic
2026-09-06 Add hardware: KiCad projects imported from the piclock repo
    Boards renamed (nixiecock1 -> nixie-board, nixiecockB -> vfd-board,
    pihat_smd -> pi-hat), socket boards moved under hardware/sockets/,
    alternative layouts under variants/, sent gerbers under fab/.
    Project-local and machine-global libraries consolidated into
    hardware/lib/ (SamacSys_Parts vendored from the global KiCad 6 mouser
    lib, TL1105CF160Q merged in). 3D model paths rewritten to
    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
    [in14board.kicad_pcb, in14board.kicad_sch, in14board_prefill.kicad_pcb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]
2026-09-06 Restructure for the monorepo: root README, .gitignore, single LICENSE
    Sub-project LICENSE files were byte-identical copies of the root GPLv3
    and are removed. CODEOWNERS moved to the repository root. Root README
    describes the new layout, root .gitignore covers KiCad, PlatformIO and
    Python artefacts.
2026-09-06 Add .gitattributes for KiCad text formats and binary assets
2026-09-06 random hw project file updates after opening the projects in KiCad 10
2026-09-06 Fix SamacSys_Parts.pretty not loading in KiCad 10
    RASPBERRYPIZEROWV13.kicad_mod had zero-height np_thru_hole pads
    (size 2.8 0), which KiCad 10 rejects; a single unreadable file makes
    the whole .pretty library fail, so every SamacSys_Parts footprint on
    nixie-board and vfd-board reported as not found. Pad size set to
    2.8 2.8. Documented how library resolution was verified and which
    remaining warnings come from upstream KiCad library renames.
2026-09-06 some resaves
    [nixie-board.kicad_sch]
2026-09-06 Add library tables to hardware variants/ directories
    KiCad treats the directory of the opened .kicad_pro as the project root,
    so variant layouts opened directly could not see the shared libraries
    and fell back to the global SamacSys_Parts entry. Each variants/ dir
    now has the same tables as its board, one level deeper. Verified with
    headless DRC on all 13 variant PCBs. Documented more upstream KiCad
    library renames.
2026-09-06 pi-hat: make the rounded-track layout the current PCB
    pi-hat.kicad_pcb is now the layout that was actually fabricated
    (rounded tracks, ex pihat_smd-rounded-blah); the previous straight-
    track layout moves to variants/pi-hat_unrounded with its own project
    file. The four solder-mask-bridge DRC exclusions from the rounded
    layout's project file were carried over into pi-hat.kicad_pro.
    [pi-hat.kicad_pcb, pi-hat_rounded-blah.kicad_pcb, pi-hat_unrounded.kicad_pcb]
2026-09-06 Point standard 3D model references at .step files
    KiCad 6 wrote ${KICAD6_3DMODEL_DIR}/....wrl references. KiCad 9+ ships
    only .step models and does not fall back from .wrl, so every
    standard-library part was missing in the 3D viewer (verified with
    kicad-cli pcb export step: 126 missing-model messages before, 0 for
    nixie-board sockets after, apart from five models that no longer exist
    upstream). Rewrote 520 references in 21 PCB files, extension only; the
    versioned variable is remapped by KiCad itself.
    [in14board.kicad_pcb, in14board_prefill.kicad_pcb, neonBoard.kicad_pcb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]
2026-09-06 old poop removed
    [xprmnt1.kicad_pcb, xprmnt1.kicad_sch, xprmnt2-bom.csv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]
2026-09-06 a resave
    [pi-hat.kicad_sch]
